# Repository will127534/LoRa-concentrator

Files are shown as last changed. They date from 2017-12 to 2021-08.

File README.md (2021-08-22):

# LoRa-concentrator

A Real opensource LoRa Gateway using SX1301/SX1308 and SX1255/SX1257
For RRI and RPI Zero

**Version 3**
---
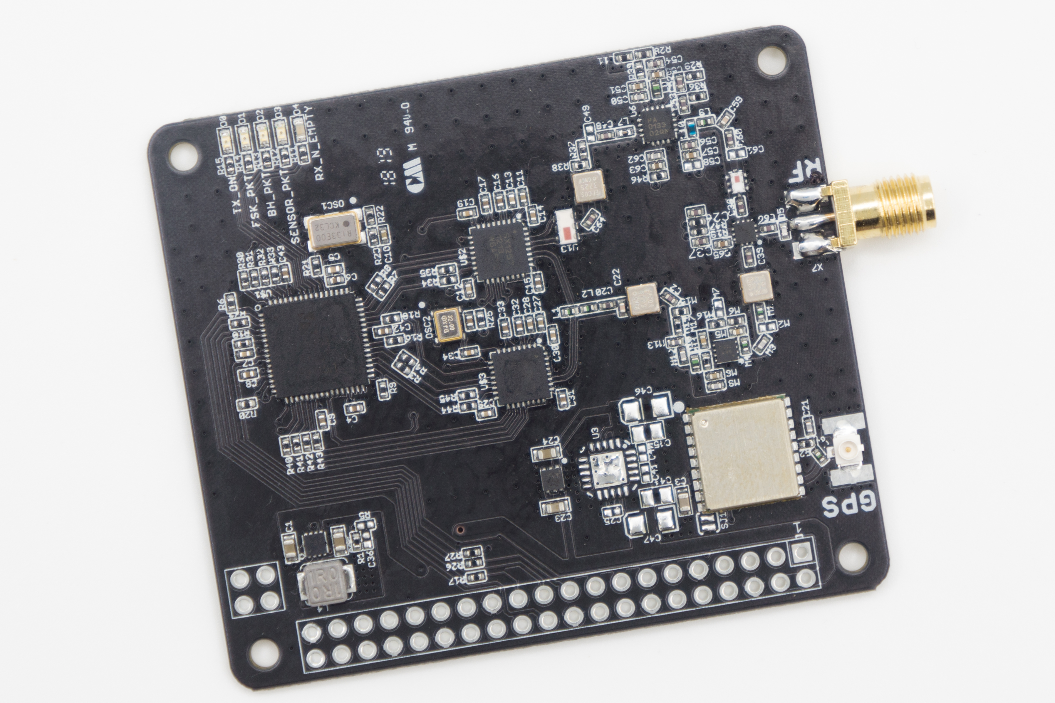
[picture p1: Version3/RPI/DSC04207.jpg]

Version 3 is designed for Raspberry Pi, same setup like Version 2, but I added LNA/PA and RF switch, and move to 4-layer board design
PA(RFPA0133) and RF switch(RFSW1012) is same as Microchip's LoRa gateway, but I changed LNA to SKY67150-396LF which have a much better Noise Figure(0.28dB).
Also note that I also used a wide bandwidth ceramic balun(800-1000Mhz) instead of discrete balun.

868Mhz and 915Mhz is mostly the same, just need to change four filter, both part number are in PCB files and BOM file. 

For power supply, 1.8V DC-DC step down has changed to TPS62061, but it is pin-to-pin replaceable with ETA3410. For 3.3V RF power, there is two option,
one is TPS7A470, which is a Ti's high-end LDO with 4 µVRMS noise, and 55dB PSRR, the other one is LP5912-3.3, which is cheaper but still gets 12 µVRMS noise and 75dB PSRR.

GPS module is still Max-7Q, which provide PPS to SX1301/8 and Raspberry Pi(GPIO05),
and provide NEMA through Raspberry Pi's UART port. There is a jumper for shuting down GPS module if you want to stack other board.

Lastly, it support PoE header on Raspberry Pi 3B+, so you can stack PoE hat on top of the board.(Just make it clear that the board doesn't have PoE on board, but just the pin header to support other PoE hat).

And is currently sold on Tindle!
https://www.tindie.com/products/will123321/sx1308-raspberry-pi-zero-lora-gateway-board/
https://www.tindie.com/products/will123321/sx1308-raspberry-pi-lora-gateway-board/

Update: 2021/08/22: The board has sold out!

**Version 2**
---
Version 2 is designed for Raspberry Pi and another board for Pi Zero


for Raspberry Pi, there is two SX125X, but for Pi Zero I strip down Radio_A for better layout.
Both of them have a Max-7Q GPS module, which provide PPS to SX1301 and Raspberry Pi(GPIO05),
and provide NEMA through Raspberry Pi's UART port. There's also a jumper for shuting down GPS module if you want to stack other board.

At the RF frontend, the main difference is that I didn't combine RX/TX using a RF switch,
and there is no on-board PA/LNA, but I did put a SAW filter. The reason not to is that I can use external LNA which is right under the antenna, there is a bias inductor right after RX port, which is connected to Raspberry Pi's 5V power rail.  

The current RPI version is designed for SX1257, but it is easy to migrate to SX1255, just put SX1255 on SX1257 and change RF passive components according to SX1255 datasheet.

I've tested both SX1255 & SX1257, and also two SX1301 connected to Raspberry Pi at the same time (there is a jumper for CE0/CE1).

last but not least, I've launch some High Altitude Balloon and using it as my multi-channel receiver. Which reach about 100Km by BW 125Khz CR 4/5 SF 7 @ 432Mhz with 16dBm power + MAX2640 LNA.

**Version 1**
---
note that I haven't get it working yet, stuck in PLL lock  
but SPI test seems to be OK.  



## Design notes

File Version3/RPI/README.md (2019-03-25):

# RPi IO Mapping

| Function | RPi Pin  | RPi IO Names |
| --- | --- | --- |
| SPI MOSI | 19 | SPI-MOSI, GPIO10 |
| SPI MISO | 21 | SPI-MISO, GPIO9 |
| SPI SCK | 23 | SPI-SCLK, GPIO11 |
| SPI CSN | 24 OR 26 | SPI-CS0, GPIO8 OR SPI-CS1, GPIO7 |
| Reset | 22 | GPIO25 |
| GPS UART TX | 10 | UART0-RX, GPIO15 |
| GPS UART RX | 8 | UART0-TX, GPIO14 |
| GPS PPS | 29 | GPIO5 |

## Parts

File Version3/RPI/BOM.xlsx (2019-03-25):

Qty | Value | Device | Package | Parts | Description
1 | LXES15AAA1-133 | D | C0402 | D5
1 | 0900BL18B100 | BALUN_1206 | BALUN_1206 | U13
1 | 0868LP15A020/0915LP15B026 | LowPassFilter | LowPassFilter | U$6
14 | 0R | R-0402 | R0402 | M16, R1, R9, R10, R17, R21, R22, R23, R24, R25, R26, R27, M14, L11
2 | 1000pF | CAP-0402 | C0402 | M5, M17
6 | 100R | R-0402 | R0402 | R3, R4, R7, R8, R16, R18
15 | 100nF | CAP-0402 | C0402 | C4, C6, C8, C9, C15, C16, C17, C18, C31, C32, C33, C42, C43, C63, C65
1 | 100nH | RF INDUCTOR | L0402 | M4
2 | 100pF | CAP-0402 | C0402 | C50, C62
8 | 10K | R-0402 | R0402 | R6, R20, R30, R32, R33, R40, R42, R43
1 | 10R | R-0402 | R0402 | R2
4 | 10nF | CAP-0402 | C0402 | C10, C11, C27, M8
1 | 10nH | RF INDUCTOR | L0402 | M10
2 | 10pF | CAP-0402 | C0402 | M9, M12
1 | 10uF | C-0603 | C0603 | C3
4 | 10uF | CAP-0603 | C0603 | C1, C23, C24, C35
1 | 150R | R-0402 | R0402 | R38
1 | 18nH | RF INDUCTOR | L0402 | L10
1 | 1K | CAP-0402 | C0402 | M15
2 | 1K | R-0402 | R0402 | R31, R41
2 | 1nF | CAP-0402 | C0402 | C19, C34
7 | 1uF | CAP-0402 | C0402 | C7, C12, C13, C14, C28, C29, C30
1 | 1uH | L'1616BZ' | 1616BZ | L4
1 | 2.2pF | CAP-0402 | C0402 | M13
3 | 2.2uF | CAP-0402 | C0402 | C51, C55, C57
1 | 2.7nH | RF INDUCTOR | L0402 | L9
1 | 20pF | CAP-0402 | C0402 | M3
1 | 22uF | CAP-0402 | C0402 | C5
1 | 3.9R | R-0402 | R0402 | R28
4 | 300R | R-0402 | R0402 | R19, R29, R36, R47
4 | 330R | R-0402 | R0402 | R34, R35, R44, R45
2 | 36.5R | R-0402 | R0402 | R37, R46
5 | 470R | R-0402 | R0402 | R11, R12, R13, R14, R15
1 | 49.9R | R-0402 | R0402 | R39
2 | 5.6pF | CAP-0402 | C0402 | C22, C59
1 | 562R | R-0402 | R0402 | M11
14 | 56pF | CAP-0402 | C0402 | C2, C20, C26, C37, C38, C39, C48, C52, C53, C54, C56, C60, C64, C66
1 | 6.8nH | RF INDUCTOR | L0402 | L8
1 | 8.2nH | CAP-0402 | C0402 | M1
1 | 8.2nH | RF INDUCTOR | L0402 | L7
1 | 9.1K | R-0402 | R0402 | M6
3 | B39921B3728U410/B39871B3717U410 | EPCOS_SAW_FILTER | EPCOS_SAW_FILTER | U$4, U$8, U$9
1 | GRM1555C1E470JZ01 | C-0402 | C0402 | C21
4 | Green | LED-0603 | LED-0603 | D0, D1, D2, D3
1 | LP5912 | LP5912 | WSON6 | U$5
1 | LQG15HS27NJ02 | RF INDUCTOR | L0402 | L6
1 | LQG15HS33NJ02D | RF INDUCTOR | L0402 | L1
1 | LQG15HS3N9C02D | RF INDUCTOR | L0402 | L2
1 | MAX-7Q-0(18p-10x9.6mm) | MODULE-GPS-SMD-MAX-7Q-0(18P-9.6X10MM) | GPS18P-SMD-1.1-10X9.6MM | GPS
1 | 32Mhz TXCO | OSCILLATOR | CRYSTAL-OSC-SMD-3.2X2.5 | OSC2
1 | 133Mhz | OSCILLATOR5X3-PIN1-INDICATED | CRYSTAL-OSC-SMD-5X3 | OSC1
1 | RASPI_BOARD_B+#_H | RASPI_BOARD_B+#_H | RASPI_BOARD_B+HAT | X1
1 | RFPA0133 | RFPA0133 | QFN16-3X3MM | U6
1 | RFSW1012 | RFSW1012 | QFN12-2X2MM | U$7
1 | Red | LED-0603 | LED-0603 | D4
1 | SKY67150_396LF | SKY67150_396LF | 8DFN | U$10
2 | SX1255 | SX1255 | QFN32G-0.5-5X5MM | U$2, U$3
1 | SX1301 | SX1301 | QFN64G-0.5-9X9MM | U$1
1 | TPS62061 | PMIC-ETA3410D2I-T(DFN8-2X2)WSON | WSON | U1
1 | uFL | SMACONNECTOR_EDGE_UFL | SMA_EDGELAUNCH_UFL | X4
1 | SMA | SMACONNECTOR_EDGE_UFL | SMA_EDGELAUNCH_UFL | X7

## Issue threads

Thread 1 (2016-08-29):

bad voltage regulator

nestorayuso, 2016-08-29:
Hi,

I see in your schematic you are using a XC6204 voltage regulators for 1.8 and 3.3 outputs from a 5v source.
This regulator has only 150mA max output current. This is insufficient.

SX1301 need 550mA typ, 750mA max @ 1.8v and 5mA typ, 10mA max @ 3.3v.

Even if you put a bigger LDO with 1A or more, the LDO will get very very hot, it will dissipate (5-1.8)*0.55= 1.76W of energy in hot.
I recommend to use a (step-down, DCDC converter...) switching regulator not linear regulator.

will127534, 2016-08-30:
Hi nestorayuso,
Thanks for pointing out the problem.
XC6204 is actually just for general SOT-23 LDO package, I solder RT9193-18PB for 1.8v and SPX3819M5-L-3.3 for 3.3v.

But you are right, it is insufficient for SX1301, I'll change the 1.8v power rail design to step-down next version.

Thanks for the comment.

hallard, 2016-08-31:
For testing may be you can use dual output DC/DC step down like that,
http://www.ebay.com/itm/DC-DC-Buck-Converter-Step-Down-Module-Power-Supply-1-5v-1-8v-3-3v-2A-Dual-Output-/262539347063

Not sure of quality but may be testing worth it.

will127534, 2016-09-02:
Hi hallard,
thanks for the advice, maybe I'll look for that IC, looks very nice (2-in-1 chip)
I'm using Lab power supply for testing though.
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
well I guess that SX1301 is dead, 1.8V rail only output 80mA, nowhere near the 700mA

This is the Log of util_pkt_logger:

loragw_pkt_logger: INFO: found global configuration file global_conf.json, trying to parse it
loragw_pkt_logger: INFO: global_conf.json does contain a JSON object named SX1301_conf, parsing SX1301 parameters
loragw_pkt_logger: INFO: lorawan_public 1, clksrc 0
lgw_board_setconf:361: Note: board configuration; lorawan_public:1, clksrc:0
loragw_pkt_logger: INFO: radio 0 enabled (type SX1255), center frequency 433000000, RSSI offset -166.000000, tx enabled 1
lgw_rxrf_setconf:415: Note: rf_chain 0 configuration; en:1 freq:433000000 rssi_offset:-166.000000 radio_type:1 tx_enable:1
loragw_pkt_logger: INFO: radio 1 enabled (type SX1255), center frequency 437000000, RSSI offset -166.000000, tx enabled 0
lgw_rxrf_setconf:415: Note: rf_chain 1 configuration; en:1 freq:437000000 rssi_offset:-166.000000 radio_type:1 tx_enable:0
loragw_pkt_logger: INFO: LoRa multi-SF channel 0 enabled, radio 1 selected, IF -400000 Hz, 125 kHz bandwidth, SF 7 to 12
lgw_rxif_setconf:519: Note: LoRa 'multi' if_chain 0 configuration; en:1 freq:-400000 SF_mask:0x7e
loragw_pkt_logger: INFO: LoRa multi-SF channel 1 enabled, radio 1 selected, IF -200000 Hz, 125 kHz bandwidth, SF 7 to 12
lgw_rxif_setconf:519: Note: LoRa 'multi' if_chain 1 configuration; en:1 freq:-200000 SF_mask:0x7e
loragw_pkt_logger: INFO: LoRa multi-SF channel 2 enabled, radio 1 selected, IF 0 Hz, 125 kHz bandwidth, SF 7 to 12
lgw_rxif_setconf:519: Note: LoRa 'multi' if_chain 2 configuration; en:1 freq:0 SF_mask:0x7e
loragw_pkt_logger: INFO: LoRa multi-SF channel 3 enabled, radio 0 selected, IF -400000 Hz, 125 kHz bandwidth, SF 7 to 12
lgw_rxif_setconf:519: Note: LoRa 'multi' if_chain 3 configuration; en:1 freq:-400000 SF_mask:0x7e
loragw_pkt_logger: INFO: LoRa multi-SF channel 4 enabled, radio 0 selected, IF -200000 Hz, 125 kHz bandwidth, SF 7 to 12
lgw_rxif_setconf:519: Note: LoRa 'multi' if_chain 4 configuration; en:1 freq:-200000 SF_mask:0x7e
loragw_pkt_logger: INFO: LoRa multi-SF channel 5 enabled, radio 0 selected, IF 0 Hz, 125 kHz bandwidth, SF 7 to 12
lgw_rxif_setconf:519: Note: LoRa 'multi' if_chain 5 configuration; en:1 freq:0 SF_mask:0x7e
loragw_pkt_logger: INFO: LoRa multi-SF channel 6 enabled, radio 0 selected, IF 200000 Hz, 125 kHz bandwidth, SF 7 to 12
lgw_rxif_setconf:519: Note: LoRa 'multi' if_chain 6 configuration; en:1 freq:200000 SF_mask:0x7e
loragw_pkt_logger: INFO: LoRa multi-SF channel 7 enabled, radio 0 selected, IF 400000 Hz, 125 kHz bandwidth, SF 7 to 12
lgw_rxif_setconf:519: Note: LoRa 'multi' if_chain 7 configuration; en:1 freq:400000 SF_mask:0x7e
loragw_pkt_logger: INFO: LoRa standard channel enabled, radio 1 selected, IF -200000 Hz, 250000 Hz bandwidth, SF 7
lgw_rxif_setconf:493: Note: LoRa 'std' if_chain 8 configuration; en:1 freq:-200000 bw:2 dr:2
loragw_pkt_logger: INFO: FSK channel enabled, radio 1 selected, IF 300000 Hz, 125000 Hz bandwidth, 50000 bps datarate
lgw_rxif_setconf:549: Note: FSK if_chain 9 configuration; en:1 freq:300000 bw:3 dr:50000 (50000 real dr) sync:0xC194C1
loragw_pkt_logger: INFO: global_conf.json does contain a JSON object named gateway_conf, parsing gateway parameters
loragw_pkt_logger: INFO: gateway MAC address is configured to AA555A9000000000
loragw_pkt_logger: INFO: found local configuration file local_conf.json, trying to parse it
loragw_pkt_logger: INFO: local_conf.json does not contain a JSON object named SX1301_conf
loragw_pkt_logger: INFO: local_conf.json does contain a JSON object named gateway_conf, parsing gateway parameters
loragw_pkt_logger: INFO: gateway MAC address is configured to AA555A9000000101
lgw_connect:524: INFO: no FPGA detected or version not supported (v0)
Note: success connecting the concentrator
setup_sx125x:495: Note: SX125x #0 version register returned 0x07
setup_sx125x:500: Note: SX125x #0 clock output enabled
setup_sx125x:557: Note: SX125x #0 PLL start (attempt 1)
setup_sx125x:495: Note: SX125x #1 version register returned 0x1f
setup_sx125x:503: Note: SX125x #1 clock output disabled
setup_sx125x:557: Note: SX125x #1 PLL start (attempt 1)
ERROR: Failed to load fw 1
ERROR: Version of calibration firmware not expected, actual:0 expected:2
loragw_pkt_logger: ERROR: failed to start the concentrator

Seems that PLL is locked!

nestorayuso, 2016-09-22:
Any progress?

550mA is when SX1301 is full running (8 MultiSF + LoRa + FSK receivers enabled), until not enabled 80mA can be a good value.

About PLL lock,
do you have the 133MHz oscilator running?
do you have the 32MHz oscillator running and routed to both sx1255 radios?
which one of the sx1255 radios provides clock back to the SX1301?
is sx1301 configured to receive clock source from that radio?

will127534, 2016-09-27:
133Mhz and 32Mhz are both running, I can see both osc are working, alsothe 32Mhz output from SX1255 to SX1301, seems OK
Not sure for the 133Mhz osc though, I'm using LVCMOS/LVTTL compatible osc.
32Mhz is for both SX1255, and I connected Radio A's 32Mhz out to SX1301.

yuqian08, 2016-12-10:
Hi Will, this is very interesting board, we are working on design air quality sensors project based on Lora, but we doing the node with Microchip RN2903/2483, and have some productions released, maybe we can have some corporation in future :)
I have a question, where you got those SX1301 documents and chips? from Semtech? thank you.

will127534, 2017-07-17:
Hi yuqian08 ,
I just noticed that Semtech release the full datasheet for SX1301 and SX1308.

will127534, 2017-09-01:
I've change 1.8V power reg to step-down, problem seems to be solved.
So closing this issue, thanks nestorayuso for pointing out this issue.

Closed 2017-09-01.

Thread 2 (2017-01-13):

ERROR: Version of calibration firmware not expected

will127534, 2017-01-13:
Currently this board still stuck on this problem,
Register Test passed, and I can confirm that the firmware is correct.
Here is the test_loragw_reg result.
Beginning of test for loragw_reg.c
Start of register verification
+++MATCH+++ reg number 0 read: 0 (0) default: 0 (0)
+++MATCH+++ reg number 1 read: 0 (0) default: 0 (0)
+++MATCH+++ reg number 2 read: 103 (67) default: 103 (67)
+++MATCH+++ reg number 3 read: 0 (0) default: 0 (0)
###MISMATCH### reg number 4 read: 204 (cc) default: 0 (0)
+++MATCH+++ reg number 5 read: 0 (0) default: 0 (0)
+++MATCH+++ reg number 6 read: 0 (0) default: 0 (0)
+++MATCH+++ reg number 7 read: 0 (0) default: 0 (0)
###MISMATCH### reg number 8 read: 20 (14) default: 0 (0)
+++MATCH+++ reg number 9 read: 0 (0) default: 0 (0)
###MISMATCH### reg number 10 read: 138 (8a) default: 0 (0)
+++MATCH+++ reg number 11 read: 0 (0) default: 0 (0)
+++MATCH+++ reg number 12 read: 0 (0) default: 0 (0)
+++MATCH+++ reg number 13 read: 0 (0) default: 0 (0)
+++MATCH+++ reg number 14 read: 0 (0) default: 0 (0)
+++MATCH+++ reg number 15 read: 0 (0) default: 0 (0)
+++MATCH+++ reg number 16 read: 0 (0) default: 0 (0)
+++MATCH+++ reg number 17 read: 0 (0) default: 0 (0)
+++MATCH+++ reg number 18 read: 0 (0) default: 0 (0)
+++MATCH+++ reg number 19 read: 1 (1) default: 1 (1)
+++MATCH+++ reg number 20 read: 1 (1) default: 1 (1)
+++MATCH+++ reg number 21 read: 0 (0) default: 0 (0)
+++MATCH+++ reg number 22 read: 0 (0) default: 0 (0)
+++MATCH+++ reg number 23 read: 0 (0) default: 0 (0)
+++MATCH+++ reg number 24 read: 0 (0) default: 0 (0)
+++MATCH+++ reg number 25 read: 0 (0) default: 0 (0)
+++MATCH+++ reg number 26 read: 0 (0) default: 0 (0)
+++MATCH+++ reg number 27 read: 0 (0) default: 0 (0)
+++MATCH+++ reg number 28 read: 0 (0) default: 0 (0)
+++MATCH+++ reg number 29 read: 0 (0) default: 0 (0)
+++MATCH+++ reg number 30 read: 0 (0) default: 0 (0)
+++MATCH+++ reg number 31 read: 0 (0) default: 0 (0)
+++MATCH+++ reg number 32 read: 0 (0) default: 0 (0)
+++MATCH+++ reg number 33 read: 0 (0) default: 0 (0)
+++MATCH+++ reg number 34 read: 0 (0) default: 0 (0)
+++MATCH+++ reg number 35 read: 0 (0) default: 0 (0)
+++MATCH+++ reg number 36 read: 0 (0) default: 0 (0)
+++MATCH+++ reg number 37 read: 0 (0) default: 0 (0)
+++MATCH+++ reg number 38 read: 0 (0) default: 0 (0)
+++MATCH+++ reg number 39 read: 0 (0) default: 0 (0)
+++MATCH+++ reg number 40 read: 0 (0) default: 0 (0)
+++MATCH+++ reg number 41 read: 0 (0) default: 0 (0)
+++MATCH+++ reg number 42 read: 0 (0) default: 0 (0)
+++MATCH+++ reg number 43 read: 0 (0) default: 0 (0)
+++MATCH+++ reg number 44 read: 0 (0) default: 0 (0)
+++MATCH+++ reg number 45 read: 0 (0) default: 0 (0)
+++MATCH+++ reg number 46 read: 0 (0) default: 0 (0)
+++MATCH+++ reg number 47 read: 0 (0) default: 0 (0)
+++MATCH+++ reg number 48 read: 0 (0) default: 0 (0)
+++MATCH+++ reg number 49 read: 0 (0) default: 0 (0)
+++MATCH+++ reg number 50 read: 0 (0) default: 0 (0)
+++MATCH+++ reg number 51 read: 0 (0) default: 0 (0)
+++MATCH+++ reg number 52 read: 0 (0) default: 0 (0)
+++MATCH+++ reg number 53 read: 0 (0) default: 0 (0)
+++MATCH+++ reg number 54 read: 0 (0) default: 0 (0)
+++MATCH+++ reg number 55 read: 0 (0) default: 0 (0)
+++MATCH+++ reg number 56 read: 0 (0) default: 0 (0)
+++MATCH+++ reg number 57 read: 0 (0) default: 0 (0)
+++MATCH+++ reg number 58 read: 0 (0) default: 0 (0)
+++MATCH+++ reg number 59 read: 0 (0) default: 0 (0)
+++MATCH+++ reg number 60 read: 0 (0) default: 0 (0)
+++MATCH+++ reg number 61 read: 0 (0) default: 0 (0)
+++MATCH+++ reg number 62 read: 0 (0) default: 0 (0)
+++MATCH+++ reg number 63 read: 0 (0) default: 0 (0)
+++MATCH+++ reg number 64 read: 0 (0) default: 0 (0)
+++MATCH+++ reg number 65 read: 0 (0) default: 0 (0)
+++MATCH+++ reg number 66 read: 0 (0) default: 0 (0)
+++MATCH+++ reg number 67 read: 0 (0) default: 0 (0)
+++MATCH+++ reg number 68 read: 0 (0) default: 0 (0)
+++MATCH+++ reg number 69 read: 0 (0) default: 0 (0)
+++MATCH+++ reg number 70 read: 0 (0) default: 0 (0)
+++MATCH+++ reg number 71 read: 0 (0) default: 0 (0)
+++MATCH+++ reg number 72 read: 0 (0) default: 0 (0)
+++MATCH+++ reg number 73 read: 0 (0) default: 0 (0)
+++MATCH+++ reg number 74 read: 0 (0) default: 0 (0)
+++MATCH+++ reg number 75 read: 0 (0) default: 0 (0)
+++MATCH+++ reg number 76 read: 0 (0) default: 0 (0)
+++MATCH+++ reg number 77 read: 0 (0) default: 0 (0)
+++MATCH+++ reg number 78 read: 0 (0) default: 0 (0)
+++MATCH+++ reg number 79 read: 0 (0) default: 0 (0)
+++MATCH+++ reg number 80 read: 0 (0) default: 0 (0)
+++MATCH+++ reg number 81 read: 0 (0) default: 0 (0)
+++MATCH+++ reg number 82 read: 1 (1) default: 1 (1)
+++MATCH+++ reg number 83 read: 1 (1) default: 1 (1)
+++MATCH+++ reg number 84 read: 0 (0) default: 0 (0)
+++MATCH+++ reg number 85 read: 1 (1) default: 1 (1)
+++MATCH+++ reg number 86 read: 0 (0) default: 0 (0)
+++MATCH+++ reg number 87 read: 0 (0) default: 0 (0)
+++MATCH+++ reg number 88 read: 0 (0) default: 0 (0)
+++MATCH+++ reg number 89 read: 0 (0) default: 0 (0)
+++MATCH+++ reg number 90 read: 7 (7) default: 7 (7)
+++MATCH+++ reg number 91 read: 240 (f0) default: 240 (f0)
+++MATCH+++ reg number 92 read: -384 (fffffe80) default: -384 (fffffe80)
+++MATCH+++ reg number 93 read: -128 (ffffff80) default: -128 (ffffff80)
+++MATCH+++ reg number 94 read: 128 (80) default: 128 (80)
+++MATCH+++ reg number 95 read: 384 (180) default: 384 (180)
+++MATCH+++ reg number 96 read: -384 (fffffe80) default: -384 (fffffe80)
+++MATCH+++ reg number 97 read: -128 (ffffff80) default: -128 (ffffff80)
+++MATCH+++ reg number 98 read: 128 (80) default: 128 (80)
+++MATCH+++ reg number 99 read: 384 (180) default: 384 (180)
+++MATCH+++ reg number 100 read: 0 (0) default: 0 (0)
+++MATCH+++ reg number 101 read: 0 (0) default: 0 (0)
+++MATCH+++ reg number 102 read: 0 (0) default: 0 (0)
+++MATCH+++ reg number 103 read: 7 (7) default: 7 (7)
+++MATCH+++ reg number 104 read: 0 (0) default: 0 (0)
+++MATCH+++ reg number 105 read: 0 (0) default: 0 (0)
+++MATCH+++ reg number 106 read: 0 (0) default: 0 (0)
+++MATCH+++ reg number 107 read: 0 (0) default: 0 (0)
+++MATCH+++ reg number 108 read: 0 (0) default: 0 (0)
+++MATCH+++ reg number 109 read: 0 (0) default: 0 (0)
+++MATCH+++ reg number 110 read: 0 (0) default: 0 (0)
+++MATCH+++ reg number 111 read: 0 (0) default: 0 (0)
+++MATCH+++ reg number 112 read: 0 (0) default: 0 (0)
+++MATCH+++ reg number 113 read: 1 (1) default: 1 (1)
+++MATCH+++ reg number 114 read: 1 (1) default: 1 (1)
+++MATCH+++ reg number 115 read: 1 (1) default: 1 (1)
+++MATCH+++ reg number 116 read: 1 (1) default: 1 (1)
+++MATCH+++ reg number 117 read: 1 (1) default: 1 (1)
+++MATCH+++ reg number 118 read: 1 (1) default: 1 (1)
+++MATCH+++ reg number 119 read: 4 (4) default: 4 (4)
+++MATCH+++ reg number 120 read: 4 (4) default: 4 (4)
+++MATCH+++ reg number 121 read: 4 (4) default: 4 (4)
+++MATCH+++ reg number 122 read: 4 (4) default: 4 (4)
+++MATCH+++ reg number 123 read: 4 (4) default: 4 (4)
+++MATCH+++ reg number 124 read: 4 (4) default: 4 (4)
+++MATCH+++ reg number 125 read: 4 (4) default: 4 (4)
+++MATCH+++ reg number 126 read: 4 (4) default: 4 (4)
+++MATCH+++ reg number 127 read: 5 (5) default: 5 (5)
+++MATCH+++ reg number 128 read: 0 (0) default: 0 (0)
+++MATCH+++ reg number 129 read: 4092 (ffc) default: 4092 (ffc)
+++MATCH+++ reg number 130 read: 7 (7) default: 7 (7)
+++MATCH+++ reg number 131 read: 0 (0) default: 0 (0)
+++MATCH+++ reg number 132 read: 0 (0) default: 0 (0)
+++MATCH+++ reg number 133 read: 0 (0) default: 0 (0)
+++MATCH+++ reg number 134 read: 1 (1) default: 1 (1)
+++MATCH+++ reg number 135 read: 1 (1) default: 1 (1)
+++MATCH+++ reg number 136 read: 0 (0) default: 0 (0)
+++MATCH+++ reg number 137 read: 0 (0) default: 0 (0)
+++MATCH+++ reg number 138 read: 0 (0) default: 0 (0)
+++MATCH+++ reg number 139 read: 29 (1d) default: 29 (1d)
+++MATCH+++ reg number 140 read: 9 (9) default: 9 (9)
+++MATCH+++ reg number 141 read: 2 (2) default: 2 (2)
+++MATCH+++ reg number 142 read: 1 (1) default: 1 (1)
+++MATCH+++ reg number 143 read: 0 (0) default: 0 (0)
+++MATCH+++ reg number 144 read: 1 (1) default: 1 (1)
+++MATCH+++ reg number 145 read: 2 (2) default: 2 (2)
+++MATCH+++ reg number 146 read: 10 (a) default: 10 (a)
+++MATCH+++ reg number 147 read: 1 (1) default: 1 (1)
+++MATCH+++ reg number 148 read: 1 (1) default: 1 (1)
+++MATCH+++ reg number 149 read: 8 (8) default: 8 (8)
+++MATCH+++ reg number 150 read: 2 (2) default: 2 (2)
+++MATCH+++ reg number 151 read: 0 (0) default: 0 (0)
+++MATCH+++ reg number 152 read: 255 (ff) default: 255 (ff)
+++MATCH+++ reg number 153 read: 1 (1) default: 1 (1)
+++MATCH+++ reg number 154 read: 0 (0) default: 0 (0)
+++MATCH+++ reg number 155 read: 8 (8) default: 8 (8)
+++MATCH+++ reg number 156 read: 7 (7) default: 7 (7)
+++MATCH+++ reg number 157 read: 1 (1) default: 1 (1)
+++MATCH+++ reg number 158 read: 1 (1) default: 1 (1)
+++MATCH+++ reg number 159 read: 1 (1) default: 1 (1)
+++MATCH+++ reg number 160 read: 1 (1) default: 1 (1)
+++MATCH+++ reg number 161 read: 1 (1) default: 1 (1)
+++MATCH+++ reg number 162 read: 0 (0) default: 0 (0)
+++MATCH+++ reg number 163 read: 0 (0) default: 0 (0)
+++MATCH+++ reg number 164 read: 0 (0) default: 0 (0)
+++MATCH+++ reg number 165 read: 0 (0) default: 0 (0)
+++MATCH+++ reg number 166 read: 0 (0) default: 0 (0)
+++MATCH+++ reg number 167 read: 0 (0) default: 0 (0)
+++MATCH+++ reg number 168 read: 1 (1) default: 1 (1)
+++MATCH+++ reg number 169 read: 32 (20) default: 32 (20)
+++MATCH+++ reg number 170 read: 100 (64) default: 100 (64)
+++MATCH+++ reg number 171 read: 100 (64) default: 100 (64)
+++MATCH+++ reg number 172 read: 7 (7) default: 7 (7)
+++MATCH+++ reg number 173 read: 5 (5) default: 5 (5)
+++MATCH+++ reg number 174 read: 8 (8) default: 8 (8)
+++MATCH+++ reg number 175 read: 0 (0) default: 0 (0)
+++MATCH+++ reg number 176 read: 0 (0) default: 0 (0)
+++MATCH+++ reg number 177 read: 0 (0) default: 0 (0)
+++MATCH+++ reg number 178 read: 0 (0) default: 0 (0)
+++MATCH+++ reg number 179 read: 0 (0) default: 0 (0)
+++MATCH+++ reg number 180 read: 0 (0) default: 0 (0)
+++MATCH+++ reg number 181 read: 0 (0) default: 0 (0)
+++MATCH+++ reg number 182 read: 0 (0) default: 0 (0)
+++MATCH+++ reg number 183 read: 0 (0) default: 0 (0)
+++MATCH+++ reg number 184 read: 1 (1) default: 1 (1)
+++MATCH+++ reg number 185 read: 2 (2) default: 2 (2)
+++MATCH+++ reg number 186 read: 0 (0) default: 0 (0)
+++MATCH+++ reg number 187 read: 0 (0) default: 0 (0)
+++MATCH+++ reg number 188 read: 0 (0) default: 0 (0)
+++MATCH+++ reg number 189 read: 0 (0) default: 0 (0)
+++MATCH+++ reg number 190 read: 0 (0) default: 0 (0)
+++MATCH+++ reg number 191 read: 0 (0) default: 0 (0)
+++MATCH+++ reg number 192 read: 0 (0) default: 0 (0)
+++MATCH+++ reg number 193 read: 0 (0) default: 0 (0)
+++MATCH+++ reg number 194 read: 5 (5) default: 5 (5)
+++MATCH+++ reg number 195 read: 0 (0) default: 0 (0)
+++MATCH+++ reg number 196 read: 1 (1) default: 1 (1)
+++MATCH+++ reg number 197 read: 0 (0) default: 0 (0)
+++MATCH+++ reg number 198 read: 0 (0) default: 0 (0)
+++MATCH+++ reg number 199 read: 0 (0) default: 0 (0)
+++MATCH+++ reg number 200 read: 0 (0) default: 0 (0)
+++MATCH+++ reg number 201 read: 1 (1) default: 1 (1)
+++MATCH+++ reg number 202 read: 1 (1) default: 1 (1)
+++MATCH+++ reg number 203 read: 2 (2) default: 2 (2)
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
9600, 2017-01-29:
I saw something like this with an iC880A concentrator board when I accidentally had the current limited on a bench PSU set too low. It sort of appeared to work, but I got bogus messages about firmware versions being wrong and the packet forwarder would not start.

will127534, 2017-09-01:
I think the problem might cause by the reset line, I didn't have a resistor to pull down.
I left it floating during first couple time of testing,  and it might blow up the whole chip.

Anyway, this problem is not happened on my version 2, so closing this issue.

Closed 2017-09-01.

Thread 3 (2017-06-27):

Usage

alexanderplanar, 2017-06-27:
Hi! I'm interesting this project, I need to create a simple gateway for LoRa.
How to use this board? I mean, this is project, as I understand, provides the physical layer, what I should use  to connect this layer to LoRa server?
For example, I found the project group [LoRa-net on github](https://github.com/Lora-net), I installed and setup LoRa-Gateway-Bridge, LoRa-Network-Server and LoRa-Application-Server on VirtualBox.
How to put it together?

mikini, 2017-07-06:
As I understand it, this board carries similar functionality as the [IMST iC880a concentrator](http://webshop.imst.de/ic880a-spi-lorawan-concentrator-868mhz.html) often used in [DIY TTN gateways](https://github.com/ttn-zh/ic880a-gateway/wiki) together with a Raspberry Pi. See the setup with a Pi in issue #1.

This board however is completely open hardware, but at the moment the design only carries a [sx1255](http://www.semtech.com/wireless-rf/rf-transceivers/sx1255/) (for 915MHz regions). For me located in Europe I'd need it tweaked for a [sx1257](http://www.semtech.com/wireless-rf/rf-transceivers/sx1257/) (868MHz) to be useful. I haven't looked into the details, yet, but are very interested too.

Seems like it is still under bring-up, though.

will127534, 2017-09-01:
Bring-up is completed guys, using version 2 hardware.
You can changed to SX1257 simply replace SX1255, it is pin compatible, but needs to change RF filter according to datasheet.

Closed 2017-09-01.

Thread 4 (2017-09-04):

Unreliable RF receive

will127534, 2017-09-04:
Testing Setup: one Transmitter @ 433.5Mhz, config Radio_B to 433.2Mhz and two channel with IF 0Khz and +3Khz.

Problem: the transmitter is transmitting package one per second (confirm by other SX1278), but SX1301 cannot receive package reliably, receive a package for a couple seconds, as the log show below.

> pi@raspberrypi:~/lora_gateway/util_pkt_logger $ ./util_pkt_logger
loragw_pkt_logger: INFO: found global configuration file global_conf.json, trying to parse it
loragw_pkt_logger: INFO: global_conf.json does contain a JSON object named SX1301_conf, parsing SX1301 parameters
loragw_pkt_logger: INFO: lorawan_public 1, clksrc 1
lgw_board_setconf:427: Note: board configuration; lorawan_public:1, clksrc:1
loragw_pkt_logger: INFO: radio 0 enabled (type SX1255), center frequency 433000000, RSSI offset -166.000000, tx enabled 0, tx_notch_freq 0
lgw_rxrf_setconf:488: Note: rf_chain 0 configuration; en:1 freq:433000000 rssi_offset:-166.000000 radio_type:1 tx_enable:0 tx_notch_freq:0
loragw_pkt_logger: INFO: radio 1 enabled (type SX1255), center frequency 433200000, RSSI offset -166.000000, tx enabled 1, tx_notch_freq 0
lgw_rxrf_setconf:476: WARNING: NOT A VALID TX NOTCH FILTER FREQUENCY [126000..250000]Hz
lgw_rxrf_setconf:488: Note: rf_chain 1 configuration; en:1 freq:433200000 rssi_offset:-166.000000 radio_type:1 tx_enable:1 tx_notch_freq:0
loragw_pkt_logger: INFO: LoRa multi-SF channel 0 enabled, radio 1 selected, IF 0 Hz, 125 kHz bandwidth, SF 7 to 12
lgw_rxif_setconf:607: Note: LoRa 'multi' if_chain 0 configuration; en:1 freq:0 SF_mask:0x7e
loragw_pkt_logger: INFO: LoRa multi-SF channel 1 enabled, radio 1 selected, IF 300000 Hz, 125 kHz bandwidth, SF 7 to 12
lgw_rxif_setconf:607: Note: LoRa 'multi' if_chain 1 configuration; en:1 freq:300000 SF_mask:0x7e
loragw_pkt_logger: INFO: LoRa multi-SF channel 2 disabled
lgw_rxif_setconf:515: Note: if_chain 2 disabled
loragw_pkt_logger: INFO: LoRa multi-SF channel 3 disabled
lgw_rxif_setconf:515: Note: if_chain 3 disabled
loragw_pkt_logger: INFO: LoRa multi-SF channel 4 disabled
lgw_rxif_setconf:515: Note: if_chain 4 disabled
loragw_pkt_logger: INFO: LoRa multi-SF channel 5 disabled
lgw_rxif_setconf:515: Note: if_chain 5 disabled
loragw_pkt_logger: INFO: LoRa multi-SF channel 6 disabled
lgw_rxif_setconf:515: Note: if_chain 6 disabled
loragw_pkt_logger: INFO: LoRa multi-SF channel 7 disabled
lgw_rxif_setconf:515: Note: if_chain 7 disabled
loragw_pkt_logger: INFO: LoRa standard channel 8 disabled
lgw_rxif_setconf:515: Note: if_chain 8 disabled
loragw_pkt_logger: INFO: FSK channel 8 disabled
lgw_rxif_setconf:515: Note: if_chain 9 disabled
loragw_pkt_logger: INFO: global_conf.json does contain a JSON object named gateway_conf, parsing gateway parameters
loragw_pkt_logger: INFO: gateway MAC address is configured to AA555A0000000000
loragw_pkt_logger: INFO: found local configuration file local_conf.json, trying to parse it
loragw_pkt_logger: INFO: local_conf.json does not contain a JSON object named SX1301_conf
loragw_pkt_logger: INFO: local_conf.json does contain a JSON object named gateway_conf, parsing gateway parameters
loragw_pkt_logger: INFO: gateway MAC address is configured to AA555A0000000101
lgw_start:819: Note: calibration started (time: 2300 ms)
lgw_start:840: Note: calibration finished (status = 197)
WARNING: calibration could not access radio A
WARNING: problem in calibration of radio A for image rejection
WARNING: problem in calibration of radio B for image rejection
Info: Initialising AGC firmware...
Info: putting back original RADIO_SELECT value
loragw_pkt_logger: INFO: concentrator started, packet can now be received
loragw_pkt_logger: INFO: Now writing to log file pktlog_AA555A0000000101_20170904T022342Z.csv
lgw_receive:1151: FIFO content: 1 10 0 5 20
lgw_receive:1170: [1 17]
Note: LoRa packet
"2017-09-04 02:23:46.551Z", 433500000,1, 1,-85, +9.8,14020300009E09E2E5C447840200000000000000000000000000000000000000"
lgw_receive:1151: FIFO content: 1 40 0 5 20
lgw_receive:1170: [1 17]
Note: LoRa packet
"2017-09-04 02:23:57.570Z", 433500000,1, 1,-85, +8.0,1F020300009E0974E6C4477F0200000000000000000000000000000000000000"
lgw_receive:1151: FIFO content: 1 70 0 5 20
lgw_receive:1170: [1 17]
Note: LoRa packet
"2017-09-04 02:24:18.558Z", 433500000,1, 1,-85,+11.2,34020300009C0940E5C447840200000000000000000000000000000000000000"
lgw_receive:1151: FIFO content: 1 a0 0 5 20
lgw_receive:1170: [1 17]
Note: LoRa packet
"2017-09-04 02:24:27.555Z", 433500000,1, 1,-81,+11.2,3D020300009E0916E6C447820200000000000000000000000000000000000000"
lgw_receive:1151: FIFO content: 1 d0 0 5 20
lgw_receive:1170: [1 17]
Note: LoRa packet
"2017-09-04 02:24:32.579Z", 433500000,1, 1,-76, +9.0,42020300009E095AE5C447810200000000000000000000000000000000000000"
lgw_receive:1151: FIFO content: 1 0 1 5 20
lgw_receive:1170: [1 17]
Note: LoRa packet
"2017-09-04 02:24:59.563Z", 433500000,1, 1,-79, +9.2,5D02030000A0096AE5C447830200000000000000000000000000000000000000"

The problem may cause by
1. Unstable Crystal (I'm using normal OSC now)
2. missing inductor at SX1255 input RF
3. missing SAW

So currently I'm going to get some TCXO, inductor, and SAW to see if any of them helps.

will127534, 2017-09-04:
also note that if I'm using single channel with SX1255 @ 433.5Mhz and IF =0Khz
I can not even receive a single package.

will127534, 2017-09-04:
TCXO doesn't help, confirmed.

will127534, 2017-09-04:
OK, solved the problem
I'm using radiohead and Arduino to transmit LoRa packet
Which is using LoRa Private Sync Word, so I need to adjust Gateway to Private mode.

Closed 2017-09-04.

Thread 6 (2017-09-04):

problem in calibration of radio B for image rejection

will127534, 2017-09-04:
Not sure what happened, but it keeps notify this error

> lgw_start:845: Note: calibration finished (status = 197)
WARNING: problem in calibration of radio B for image rejection

Closed 2018-05-26.

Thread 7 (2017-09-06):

About the value of Resistance, capacitance, inductance

hyklkd, 2017-09-06:
Hello, I have download your project and found that I can't get the value of Resistance, capacitance, inductance.Could you please show me you BOM?Thank you!

will127534, 2017-10-03:
I'm currently choosing the values for PCBA, so I'll push version 2.1 later, maybe before the end of the month.

will127534, 2017-12-01:
Values for 915Mhz are up!

Closed 2017-12-01.

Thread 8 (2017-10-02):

Values

Hoel, 2017-10-02:
Hi, i am interested in such concentrator for long range temperature humidity measurements (SHT21), i notice all values are removed, any chance you update the file or follow b email?
Thank you.

will127534, 2017-10-03:
Hi hoel,
I'm currently choosing the values for PCBA, so I'll push version 2.1 later, maybe before the end of the month.

will127534, 2017-12-01:
Values for 915Mhz are up!

Closed 2017-12-01.

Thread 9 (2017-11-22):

great project！

shujun, 2017-11-22:
Great project, Merge the gateway with Raspberry pi is a good idea.
Is NDA going to be a problem?And what's the progress and roadmap?

will127534, 2017-11-23:
Thanks!
I didn't signed any NDA, so its not going to be a problem IMAO.
Currently I'm building a version for RPI, with 2xSX125x and some SAW filter.
Testing is fine, and I just sended out to PCBA factory, maybe sold some unit on tindle later this year.
The newer version sch&layout will upload later this month.

Closed 2017-12-06.

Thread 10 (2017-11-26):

Unreliable during heavy load

will127534, 2017-11-26:
Setup:
one RF98 Transmitter @ 432Mhz, transmitting 6-axis data (24byte+2byte header) per 100ms
one RPI-Gateway with full channel on

If I tested indoor, Gateway will output some error data, the full log is here
[Log](https://asciinema.org/a/72G7waVnfnynvr8EB0Rmi2gFS)
it seems that SX1301 will output some wrong data.

But I when I try it near the window(with some wind), the error goes away, so I believed that it is cause by thermal problem, maybe do some measurement later.

I've already added a heatsink on top of SX1301, but it seems not enough....

apparell, 2018-03-08:
Hello, first of all congrats for the project.
I'm an energy engineering working in an heat-sink company. Maybe I can help you.
if did you record high temp, Can you post some value?

If the problem if thermal, we can design together an enclosure w/ embed heat-sink and ventilation.
let me know.
regards,
apparell

Brat0x2, 2018-07-14:
@will127534 Hi!
I've got the the board version 3 (2018/03/28). I noticed that sx1308 is very hot (can't touche my finger)! Is it normal working conditions?
There is no any heatsink on sx1308, the board powered from Raspberry Pi over 40pin connector, uUSB power source 5V, 2A.

will127534, 2018-07-14:
@Brat0x2
Yes it is, SX1308 consume about 0.6A, which means it takes about 1W
I did measure about 55~60 Degrees on the SX1308, barely touchable...

will127534, 2018-07-14:
@Brat0x2
Depend on where if works, I have an indoor one without any heat sink and it works just fine,
But for my outdoor one, I did added a fan to cool two gateway in a box under the sun.

mikini, 2018-07-30:
You need to ensure proper transfer of thermal energy from both top (heat sink) and bottom (solder to PCB plane with substantial copper area 3 exposed to air) of the chip. To operate within the 0-70 deg. C operating conditions of the datasheet Semtech specifies 100 cm2 copper below and heatsink on top.

Let me quote from the datasheet:

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

Source: [SX1308 Datasheet, paragraph 2](https://www.semtech.com/uploads/documents/sx1308.pdf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)

And from the thermal application note:

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

Source: [SX1308 Thermal Dissipation: Technical Analysis and Recommendations, paragraph 3](https://www.semtech.com/uploads/documents/SX1308_PicoCell_GW_Thermal_Dissipation_Technical_Analysis_V1.0.pdf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)

will127534, 2018-08-05:
@mikini  That is a really useful data!
It seems that two Aluminum Heat Sink for Raspberry Pi (top and bottom) is good enough for heat dissipation. I think RPi Gateway V3 is larger than their PicoCell gateway, so using the same setup will perform better.

From the measurement on "RPIZero" Gateway V3(not released yet), I measured about 50~55 degrees with a large heatsink and 60 degrees without, which is better than PicoCell GW without housing and with heat sink. Although I didn't run for 24 Hours, only for couple hours.

Anyways, I'll do a experiment on RPI Gateway V3 later.

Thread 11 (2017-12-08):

SX1301 VS SX1308?

adz1122, 2017-12-08:
I would like to ask, what is the difference SX1301 and SX1308?
think you!

will127534, 2017-12-08:
In terms of function: No, SX1301 is same as SX1308, pin-to-pin and software compatible
But, SX1301 has -142.5 dBm sensitivity, SX1301 only have -139 dBm.

adz1122, 2017-12-08:
thinks，“But, SX1301 has -142.5 dBm sensitivity, SX1301 only have -139 dBm.”SX1301 only have -139 dBm?

will127534, 2017-12-08:
Sorry typo
Should be SX1301 has -142.5 dBm sensitivity, SX1308 only have -139 dBm.

adz1122, 2017-12-08:
thinks you， Are you doing your own gateway? I am also very interested in this, add a WeChat?
My WeChat：17512020988
I am from ShenZhen An electronic enthusiast

will127534, 2017-12-09:
Yes, I am building by own gateway.
Shenzhen is a perfect place to be electronic enthusiast, too bad that I don't have WeChat though...
如果可以講中文的話就直接打中文好了 :D

adz1122, 2017-12-09:
好的，以后多交流，你开发这个网关准备用在哪里呢，我很想用LORAWAN做些传感器用在农业上，不过我没玩过树莓派，只玩过arduino或者STM32了。

will127534, 2017-12-09:
最主要應該是用在探空儀(High Altitude Balloon)，其他的話應該就小範圍的感應器網路了，類似你說的農業用途，不過收的應該是氣體感應器與PM2.5的資料
STM32應該也能玩網關，Semtech有一個[picoGW](https://github.com/Lora-net/picoGW_mcu)
雖然picoGW還需要用電腦，但是STM32<->SX1301的HAL都在那邊，應該可以做一個獨立的網關
我有看到一些掏寶上的店家在做AT-cmd的Gateway，我猜應該是拿picoGW改的

Serjaru, 2018-10-05:
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

Can find 17512020988

bkrajendra, 2019-11-18:
Hi all Im also doing my own gateway.

goodmasher, 2020-04-21:
寡人是做射频硬件的，对于SX1257/SX1255 与 SX1301构成的网关，如何进工厂生产的测试一直找不到方法。希望大家在软件上能整个生产测试的方法。否则很难量产。

Closed 2018-05-26.

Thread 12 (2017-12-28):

GPS selection

Kiogora, 2017-12-28:
Hi,

Great work you have done so far. I also wanted to try to create a gateway myself then I stumbled on your project. I have gone through the LoRaGW userspace C code and currently they use the Ublox GPS sensors as it outputs raw GPS time, not UTC. I have not yet confirmed what the GPS time is used for but your project has motivated me to check up on it later today. Do you have info on this?

As to my questions:

1. I have some Quectel L96 and L80 parts and the most they do is give UTC time. Did you have to change the codebase to accept the quectel version NMEA strings?
2. Any plans to do a PoE version? That would be something interesting and would be willing to look into.

will127534, 2017-12-28:
Hi Kiogora,
Answering the first one: No, I replace GPS module to MAX-7Q, see #5
Second one: Yes, I'm actually deploying some gateway in the wild, and find out that I really need POE to simplify wiring, building PoE sink board is definitely is on my todo list.
But I won't build PoE with this board, there is not much space for isolated dc-dc and a large PoE RJ45 connector. Two plans here, one is to build a new POE shield for RPI, the other one is using computer module or other SBC module like MT7688 to build a PoE capable RPI-like board or single board with SX1301. I'm still finding easier PoE solution to give it a try, before then, I'll use commercial PoE injector/isolator to power RPI Gateway.

Thanks for the compliment!

Kiogora, 2017-12-30:
Thanks for the quick reply and clarification on the GPS chip.

I will go for an off the shelf solution also, for now as I chalk up a new design of a concentrator controller using the ESP32.It should be quick to port and test. I notice that you had two issues with your testing:
1. PLL lock and supposedly thermal issues. As a suggestion: You could try adding more via spaced at lambda/20 to the design to reduce the inductance on the board, especially near the RF sections that connects the ground planes. It may solve unforseen problems.

piratfm, 2019-04-05:
With such a small patch, it's possible to use ATGM336H-5N11 cheap GPS-module, which is also supports UBX messages format, required by the gateway. The only requirement - is not to connect pin 7 (NC) to the power line.

```
diff --git a/libloragw/src/loragw_gps.c b/libloragw/src/loragw_gps.c
index c0e0ded..3fd40de 100644
--- a/libloragw/src/loragw_gps.c
+++ b/libloragw/src/loragw_gps.c
@@ -529,13 +529,14 @@ enum gps_msg lgw_parse_nmea(const char *serial_buff, int buff_size) {
     } else if (match_label(serial_buff, "$G?RMC", 6, '?')) {
         /*
         NMEA sentence format: $xxRMC,time,status,lat,NS,long,EW,spd,cog,date,mv,mvEW,posMode*cs<CR><LF>
-        Valid fix: $GPRMC,083559.34,A,4717.11437,N,00833.91522,E,0.004,77.52,091202,,,A*00
+        Valid fix: $GPRMC,083559.34, A,4717.11437,N,00833.91522,E,0.004,77.52, 091202,,,A*00
+                   $GPRMC,083559.34, A,4717.11437,N,00833.91522,E,0.004,77.52, 091202,,,A,V*11
         No fix: $GPRMC,,V,,,,,,,,,,N*00
         */
         memcpy(parser_buf, serial_buff, buff_size);
         parser_buf[buff_size] = '\0';
         nb_fields = str_chop(parser_buf, buff_size, ',', str_index, ARRAY_SIZE(str_index));
-        if (nb_fields != 13) {
+        if (nb_fields < 13 || nb_fields > 14) {
             DEBUG_MSG("Warning: invalid RMC sentence (number of fields)\n");
             return IGNORED;
         }

```

mikini, 2019-04-05:
Nice, haven't seen the ATGM336H GNSS module before.

It's supposedly [LEA](http://www.icofchina.com/d/file/xiazai/2016-12-05/b5c57074f4b1fcc62ba8c7868548d18a.pdf#page=3) (possibly even [NEO and MAX](https://www.electrodragon.com/product/gnss-module-atgm336h/)) series compatible, but if your experience failing NMEA output that seems odd. Unless the loragw parser is more restrictive than the NMEA protocol dictates. It is also my previous impression that the GPS time from the UBX protocol was important. Have you verified how it behaves when [parsing the UBX-NAV-TIMEGPS packet](https://github.com/Lora-net/lora_gateway/blob/master/libloragw/src/loragw_gps.c#L441).

Just dumping some info here;

$9 on Tindie; https://www.tindie.com/products/ICStation/atgm336h-gps-bds-gnss-positioning-module12420/

On VoltLog; https://youtu.be/pfpyvJWgOqM?t=418 (warns of differing constellation support of different chip variants)

User Manual; http://www.icofchina.com/d/file/xiazai/2016-12-05/b5c57074f4b1fcc62ba8c7868548d18a.pdf

It seems to be based on the generic GNSS chipset [AT6558](http://www.icofchina.com/pro/dingwei/2016-07-29/5.html#), datasheet; http://www.icofchina.com/d/file/xiazai/2016-12-05/b1be6f481cdf9d773b963ab30a2d11d8.pdf

Info on some Western sites here:
https://www.robotics.org.za/NEO-M8N-MOD
https://www.electrodragon.com/product/gnss-module-atgm336h/

piratfm, 2019-04-05:
Here is sample of log of `./test_loragw_gps`:

```
Note: parsing UBX frame> b5 62 01 20 10 00 58 e1 b4 1b f6 ff ff ff ff 07 12 07 38 00 00 00 83 7c 24 47

~~ UBX NAV-TIMEGPS sentence, triggering synchronization attempt ~~
    * Synchronization successful *
    UTC reference time: 1554455221.000000000
    GPS reference time: 1238490438.999999989
    Internal counter reference value: 5946088
    Clock error: 1.000000000
    * Test of timestamp counter <-> GPS value conversion *
    Test value: 6446088
    Conversion to GPS: 1238490439.499999989
    Converted back: 6446088 ==> 0µs
    * Test of timestamp counter <-> UTC value conversion *
    Test value: 6446088
    Conversion to UTC: 1554455221.500000000
    Converted back: 6446088 ==> 0µs

```

The gateway periodically (once per 30s) showing such info:
```
INFO: Disabling GPS mode for concentrator's counter...
INFO: host/sx1301 time offset=(1554455463s:612158µs) - drift=-3µs
INFO: Enabling GPS mode for concentrator's counter.
```
Also it's still giving me some warnings about out-of-sync sometimes, after long time of work, but that might be bad TXCO.

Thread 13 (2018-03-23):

BOM and 868 mhz

karthirockz, 2018-03-23:
Hi Congrats and thanks for making it open source.

1. Can you please share the BOM file (bill of materials)

2. Please update LoRa-concentrator/Version2/RPI/SCH.pdf some of the labels of components are overlapped

3. What is the procedure to change it to 868 mhz

apparell, 2018-04-04:
To change the operational frequency you have to adapt passive RF components and SAW filter from the radio frequency front end. Ther's lot of resources on the web about sizing RF matching network also.
Regards!

apparell, 2018-04-04:
When Will will (WWW :D) publish the V3, I can help you to make 868 version. enjoy and happy open project!

clodpi, 2018-04-04:
@will127534 thanks, waiting for your 868 version

karthirockz, 2018-04-04:
@will127534 thanks, waiting for your 868 version

davidfungf, 2018-05-14:
Hi @will127534 , waiting for your 868 version too. Thanks.

gadLinux, 2018-06-19:
Me too. I suppose it's not as easy as change the parts you told above

Closed 2018-05-26.

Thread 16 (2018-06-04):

Can this module do LBT ? Listen before talk ?

4mig4, 2018-06-04:
It seems that HAL from SEMTECH supports LBT when version is > = 4.1.0, but can AS923 be supported by your board ? (Japan)

will127534, 2018-06-04:
No, it won't support LBT since it needs a FPGA + SX1278 to scan the channel for LBT.

Note that if anyone have the ref V1.5 design sch, I'm willing to add LBT support. 😄

4mig4, 2018-07-15:
Ok thanks and no I do not have the reference design v1.5

will127534, 2018-08-31:
Reopen this issue because it is on my todo list...

piratfm, 2019-03-20:
Schematic can be reversed from this photos: https://fccid.io/AU792U13A16859/Internal-Photos/Internal-Photos-3321124

will127534, 2019-03-20:
Almost, but you can't, because it is a multi layer board.
I'm hoping to reverse by reversing the FPGA bitstream, but I can't read verilog......

piratfm, 2019-03-21:
Yep, You are right, but on this one:
http://www.embit.eu/wp-content/uploads/fronte-retro1.png
The signal layers are top/bottom and inner - are powers. So this is good suggestion to start. Also There is correct FPGA (iCE40LP1K-CM49) to which firmware is avaliable.

4mig4, 2019-03-21:
Very to see to that you think it is a worthy thing to do.

piratfm, 2019-03-22:
Pin mapping of FPGA, correct me if I'm wrong:
```
#SPI interface to HOST
set_io SPI_MISO      A5
set_io SPI_CS        A6
set_io SPI_SCLK      A3 #Wire shared with SX1301_SCLK and EEPROM_SCLK
set_io SPI_MOSI      A4 #Wire shared with SX1301_MOSI and EEPROM_MOSI

#SPI slave 0:
set_io SX1301_GPIO1      D7
set_io SX1301_GPIO3      A2
set_io SX1301_GPIO4      B2
set_io SX1301_CSN        B3
set_io SX1301_MISO       B4
set_io SX1301_RADIO_RST  F4 #this is input, not used in FPGA fw

#SPI slave 1: FPGA itselve

#SPI slave 2:
set_io EEPROM_CSN    A7
set_io EEPROM_MISO   C4

#SPI slave 3:
set_io SX1272_MOSI   A1
set_io SX1272_NSS    E2
set_io SX1272_MISO   D2
set_io SX1272_SCK    D3
set_io SX1272_RESET  F2

#Stays in the middle between I2S interface of SX1301 and SX125X (radio A)
set_io A_SP_CLK_IN   D1
set_io A_QI_TX_IN    B1
set_io A_IQ_TX_IN    C1

set_io A_SP_CLK_OUT  F3
set_io A_IQ_TX_OUT   G3
set_io A_QI_TX_OUT   G4
```
There is some small microchip SPI eeprom, but it's not used in software.
FPGA can be replaced by more DIY-friendly with QFN48 package, like ICE5LP1K-SG48. Only pin map file must be changed (and recompile firmware with icestorm). Also SX1272 share reference clock with SX125X and receiving RF just after second SAW (have no idea about how impedance matching has been made there). Maybe I can try to it with my lattice ICE40UP5K dev board later... But first need to solder (finalize) my gateway.

will127534, 2019-03-23:
@piratfm
That was awesome!
I'm recently doing other projects that uses ICE5LP1K-SG48 (a.k.a learning verilog), so I also have some chip and boards :D
I'm glad that I left a bunch of resistor between the SPI lines, it makes it easier to modify.
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

jgriessen, 2019-08-16:
Hi,
I have customers that want LoRa gateways.  I wonder if you are available to make some V3 boards
to sell me on tindie and coach me for pay on setup of all the software to connect to lorawan thethingsnetwork?  Later, we can make improved boards, weather enclosures, etc.  Interested?  Are you trained with a BSEE degree, or hobby?  Thanks, John

PostScript:  I knew some verilog for chip design, but have forgotten most of it.  Listen before talk would be a fine feature to brag about!

symdeb, 2019-10-22:
Hope Will would (re)consider to build another batch of boards. After surveying what is low cost and available right now, Lora, in low cost form, is still not so accessible, not much  choice and this looks to be the best solution so far.  RAK(831) boards are not cheap either. Trying to build an IoT gateway (not using RPI but with STM32/NXP based embedded with SPI) and would like to add in Lora. What would be nice are small companion device development ("thing") boards to connect sensors and actuators for prototype solution  purposes.  I am in Taipei City as well.

jgriessen, 2019-11-15:
@symdeb  How is your project to build IoT gateway with STM32/NXP parts coming?  Do you use pcb-rnd to make boards?  Maybe we can collaborate to get a low cost gateway and sensor boards?  I've done work with TinyOS on sensor boards, but that OS stalled.  RIOT is the OS I am interested in now.

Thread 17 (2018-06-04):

Combining RX paths

amateusz, 2018-06-04:
I'm not a RF design expert, but shouldn't RF RX paths (N$49 at your schematic for v3) be merged using some impedance matching ? Integrated [resistor divider](http://www.radio-electronics.com/info/rf-technology-design/coupler-combiner-splitter/rf-resistive-splitter-combiner-divider.php) (losses >= 6dB) or Wilkinson divider (losses >= 3dB). They cost pennies (~$0.3).

will127534, 2018-06-04:
There is two inductor L1 and L2 and two Cap C22 with C20 for impedance matching.

Closed 2018-06-04.

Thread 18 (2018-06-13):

one antenna

EduardShaid, 2018-06-13:
What is the reason that you switched from four antennas in version 1, to one antenna in version 3?

will127534, 2018-06-13:
The first version is just want to make sure SX1301 & SX1255 is working, so to keeping everything simple, every RF path is straight from IC to SMA connector.

After I successfully boot up SX1301,  the 2nd is aimed for 8-ch receiver, so I combine the both RX and
ditch one Tx of SX125Xs, so two RF left, one TX one RX.

After the 8-ch receiver project is finished, there is some people asking for LoRawan support.
So to simplify the setup, I moved to single antenna, which combine RX/TX with RF switch and it is the current version.

EduardShaid, 2018-06-19:
Thanks for the answer, but there are still questions:

1) The project design does not include the names of TXCO. Are there any requirements for their characteristics, such as accuracy or stability?
2) What were the requirements for the motherboard material or did the conventional FR-4 take it for the board?

will127534, 2018-06-19:
1.  I'm stick with Microchip Reference Design's NT3225SA, but I think any TCXO will do the job.
2. 4-Layer FR4 for version 3, I need more layers to maintain solid ground plane with RF frontends.

EduardShaid, 2018-06-19:
Thanks.

Closed 2018-06-13.

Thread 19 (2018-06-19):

TXCO

EduardShaid, 2018-06-19:
There are still questions:

1. The project design does not include the names of TXCO. Are there any requirements for their characteristics, such as accuracy or stability?
2. What were the requirements for the motherboard material or did the conventional FR-4 take it for the board?

Thanks.

bkrajendra, 2019-11-18:
i have also asked same question at https://github.com/will127534/LoRa-concentrator/issues/38#issuecomment-552165267
But still waiting for reply from @will127534

will127534, 2019-11-18:
1.The main 133Mhz Osc doen't have a strict requirement, but the 32Mhz do, since it is the clock for RF components, the reference design uses 2725T series.
2.FR-4 will do the work.

Closed 2019-11-18.

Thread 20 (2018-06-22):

433Mhz和470Mhz频率，需要做哪些改进？

komoya, 2018-06-22:
你好!
433Mhz 和470Mhz，除了把SX1257换成SX1255，还需要对哪些元件进行更换呢？  麻烦指教。

will127534, 2018-06-22:
還有Balan要換成433Mhz的版本，PA和LNA的周邊匹配也要換一下，不過應該都有在PA/LNA的Datasheet
另外還有三個SAW filter+Low Pass Filter要換...
打字打到這邊我覺得基本上RF Frontend就只有IC沒換，其他都要...

Closed 2018-07-31.

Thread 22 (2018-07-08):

"failed to start the concentrator"

Zytheran, 2018-07-08:
I managed to get the system running and ran it say 5 times with no errors and was about to work out why the connection was not showing on the Things network when I got the error message "failed to start the concentrator".
command run was
./lora_pkt_fwd > logfile.txt

Is there a list of things to check? It seems odd that is was working one minute and not the next. [The only thing I did was shut it down to swap over the power supply for the Raspberry Pi because I was getting low voltage warnings, which in itself was a bit odd because the voltage was 5.1V and it was a 2A supply providing 300mA. Anyhow swapped PS. I wasn't sure this was a Raspberry Pi voltage error and not one from the LoPoWAN board?]
Is there a list of things to check with the LoPoWAN setup, everything was done as per the instructions.
Up to the end of the TTN network setup guide.
log file is as follows:
*** Beacon Packet Forwarder for Lora Gateway ***
Version: 4.0.1
*** Lora concentrator HAL library version info ***
Version: 5.0.1;
***
INFO: Little endian host
INFO: found global configuration file global_conf.json, parsing it
INFO: global_conf.json does contain a JSON object named SX1301_conf, parsing SX1301 parameters
INFO: lorawan_public 1, clksrc 1
INFO: no configuration for LBT
INFO: antenna_gain 0 dBi
INFO: Configuring TX LUT with 16 indexes
INFO: radio 0 enabled (type SX1257), center frequency 917200000, RSSI offset -166.000000, tx enabled 1, tx_notch_freq 0
INFO: radio 1 enabled (type SX1257), center frequency 917900000, RSSI offset -166.000000, tx enabled 0, tx_notch_freq 0
INFO: Lora multi-SF channel 0>  radio 0, IF -400000 Hz, 125 kHz bw, SF 7 to 12
INFO: Lora multi-SF channel 1>  radio 0, IF -200000 Hz, 125 kHz bw, SF 7 to 12
INFO: Lora multi-SF channel 2>  radio 0, IF 0 Hz, 125 kHz bw, SF 7 to 12
INFO: Lora multi-SF channel 3>  radio 0, IF 200000 Hz, 125 kHz bw, SF 7 to 12
INFO: Lora multi-SF channel 4>  radio 1, IF -300000 Hz, 125 kHz bw, SF 7 to 12
INFO: Lora multi-SF channel 5>  radio 1, IF -100000 Hz, 125 kHz bw, SF 7 to 12
INFO: Lora multi-SF channel 6>  radio 1, IF 100000 Hz, 125 kHz bw, SF 7 to 12
INFO: Lora multi-SF channel 7>  radio 1, IF 300000 Hz, 125 kHz bw, SF 7 to 12
INFO: Lora std channel> radio 0, IF 300000 Hz, 500000 Hz bw, SF 8
INFO: FSK channel 8 disabled
INFO: global_conf.json does contain a JSON object named gateway_conf, parsing gateway parameters
INFO: server hostname or IP address is configured to "router.au.thethings.network"
INFO: upstream port is configured to "1700"
INFO: downstream port is configured to "1700"
INFO: packets received with a valid CRC will be forwarded
INFO: packets received with a CRC error will NOT be forwarded
INFO: packets received with no CRC will NOT be forwarded
INFO: GPS serial port path is configured to "/dev/serial0"
INFO: found local configuration file local_conf.json, parsing it
INFO: redefined parameters will overwrite global parameters
INFO: local_conf.json does not contain a JSON object named SX1301_conf
INFO: local_conf.json does contain a JSON object named gateway_conf, parsing gateway parameters
INFO: gateway MAC address is configured to B827EBFFFEE3F5F6
INFO: packets received with a valid CRC will be forwarded
INFO: packets received with a CRC error will NOT be forwarded
INFO: packets received with no CRC will NOT be forwarded
INFO: [main] TTY port /dev/serial0 open for GPS synchronization
ERROR: [main] failed to start the concentrator
-----------------------------------------------
Unfortunately I don't have a log from when it used to run but I know it was quite a few more lines, the GPS went on and off and then it was doing a few push commands or something.
json files attached.

[global_conf.json.txt](https://github.com/will127534/LoRa-concentrator/files/2174222/global_conf.json.txt)
[local_conf.json.txt](https://github.com/will127534/LoRa-concentrator/files/2174223/local_conf.json.txt)

Zytheran, 2018-07-10:
Solution was to go back into the lora_gateway directory
cd ./lora_gateway/

and then start the gateway again.

Start gateway by:
./reset_lgw.sh start

and then get back onto TTN via
cd ./lora_pkt_fwd
./lora_pkt_fwd

...and all good!

As mentioned in the opening post, this issue didn't always occur after power cycle however in the headless setup when the RPi is up a pole on the roof I'll be setting up a script to start the Gateway each time it boots before the LoRa packet forwarder starts.
(BTW issue with the noshow on TTN was because you need to configure the Gateway with the "Legacy packet forwarder" option when setting up a new Gateway)

will127534, 2018-07-10:
Hi Zytheran,
Yes, you should restart the gateway every power cycle to ensure SX1308 is in the init state.
I'll update the guide for clarify, thanks 👍

Closed 2018-07-10.

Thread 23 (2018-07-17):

GPS coordinates

Brat0x2, 2018-07-17:
@will127534 Hi!
I use GPS on the board version 3 with external antenna.
I see log messages:
`### [GPS] ###`
`# Valid time reference (age: 0 sec)`
`# no valid GPS coordinates available yet`
`##### END #####`
There is no valid coordinates for a long time. Why I didn't see them at all?

will127534, 2018-07-17:
Hi @Brat0x2
It seems GPS cannot fetch enough signal for solving the location (but still able to output time reference)
Can you confirm the GPS antenna can get a good reception?

Also you can use
`screen /dev/serial0 9600`
to see the NEMA output from GPS, which have some info about the signal strength.

Brat0x2, 2018-07-17:
@will127534
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

will127534, 2018-07-17:
Yeah... It seems gps only lock  1 sat, where did you put the antenna?

Brat0x2, 2018-07-17:
@will127534 Simple external antenna with 2 meters cable, on the window to the North.

will127534, 2018-07-17:
It is active or passive antenna?
if active, 5V or 3.3V?
The GPS Antenna port will output 3.3V to active antenna, so if you were using 5v active antenna,
it may cause the problem.

Brat0x2, 2018-07-17:
@will127534 It is active GPS antenna, 2.7...5.0V

will127534, 2018-07-17:
hmm.... can you put the antenna outdoor?

Brat0x2, 2018-07-17:
There is no possibility now. I'll try as I can. Thanks for your help!

Brat0x2, 2018-08-30:
@heitorPB the problem has been solved. GPS depends on our local weather.

Closed 2019-11-18.

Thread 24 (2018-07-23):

Frequency Plan

hssounamed, 2018-07-23:
hi will
when i bot the SX1308 Raspberry Pi Lora Gateway i have chosen the 868 MHz, i wanted to ask if by simple changing the Antenna to 915 Mhz will it be possible to use it as a Lora concentrator with a frequency plan of 915 MHz after configuring the global_conf files to 915 MHz.

if that's not possible you mentioned that the difference between the 868 model and the 915 model is simply 4 filters that we need to change, so is it possible to share the BOM file for the 868 MHz.
thank you have a great week.

Closed 2018-07-26.

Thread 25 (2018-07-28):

Capacitator values

deep470, 2018-07-28:
Capacitators have voltage ratings, e.g. 5v, 10v, 25v, 50v.*

Which one do you recommend? Is 16v enough or better 25v to be sure?

Also: M15 (CAP-0402) has a value of 1K? Is that a special capacitor?

1nF = 1000pF so M5, M17 and C19, C34 are the same, right?
C3 is the same as C1, C23, C24, C35?

Sorry, my electronics knowledge hasn't been used for decades.
Thank you for your great work!

will127534, 2018-07-31:
So I normally double the voltage it handles,
for 3.3V rail => 10V or 6.3V
     1.8V => 6.3V
     5V => 10V
For the NP0 on the RF path and other small caps, their voltage rating is more then enough.

For M15, the package/sch name may cause some confusion, it is a 1K resistor, the M prefix is for impendence, so the component might be L,R or C, depends on the frequency needed.

M5,M17 should be 1500pF not 1000pF, so it is different then C19/C34
And C3 is the same as C1, C23, C24, C35

Thank you for the compliment! 👍

Closed 2018-07-31.

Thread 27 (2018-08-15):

Using LoRa-concentrator V2 on spi 0.1

hamersin, 2018-08-15:
JP1 allows selecting between SPI 0.0 and SPI 0.1. If I wanted to use SPI 0.1, what do I have to update to have the raspberry PI see the concentrator?

will127534, 2018-08-16:
You will need to change /libloragw/src/loragw_spi.native.c line 57
from /dev/spidev0.0 to /dev/spidev0.1
then recompile again.

hamersin, 2018-08-17:
Thank worked - Thanks

Closed 2018-08-17.

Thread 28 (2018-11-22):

One of sx1257 has very low RSSI

Brat0x2, 2018-11-22:
I've got the LoRa-concentrator (the board version 3), EU868 configuration.
My LoRaWAN-mote sends messages, radio0 (ch0, ch1, ch2) receives them with RSSI -27, but radio1 (ch3, ch4, ch5, ch6, ch7) receives them corrupted only on ch5 with RSSI -111.
Thus only 3 from 10 messages reaches my server.
Is it a hardware problem? Maybe the board is damaged?

will127534, 2018-11-23:
Yes, it seems to be a problem of the receiver,
and it seems that Radio B has a problem receiving the data...
Please contact me via tindle to send a replacement.

will127534, 2018-11-27:
Note: I think the problem is the SX1257 on Radio B.

Brat0x2, 2018-11-27:
@will127534 ok, thanks

Closed 2018-11-27.

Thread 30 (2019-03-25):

Component values

SG-O, 2019-03-25:
Thanks for your great design!

I'm currently picking all the parts to build my own full size V3. I have a few questions about some of the components:

L7 has a value of 8.2uH in a 0402 package. Is this really correct?
C21 is EOL and no longer available. Can I choose a different part? What are the requirements for the component?

Could you provide me with the components you use for botch oscillators? I have a hard time picking a correct model.

Thanks!

will127534, 2019-03-25:
L7 should be 8.2nH, I'll fix that typo, thanks!

C21 is decouple cap for GPS antenna power, so it is fine to replace with other similar cap,
just pick NP0 and it will be fine, the voltage rating for 47pF will be more than enough but just make sure it is larger than 6.3V

NT3225SA for 32Mhz TCXO
2725T for 133Mhz XO

will127534, 2019-04-05:
Yeah.. I think that's a little bit overkill, maybe replacing it with 100ohm will be fine.

piratfm, 2019-04-05:
The problem - is that SX1301 don't see SX125X chips on SPI bus at all with that loarge resistors. I replaced them to 0R and gateway starts working as expected.

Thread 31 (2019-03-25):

Replacement for the GPS receiver

SG-O, 2019-03-25:
Would it be possible to replace the Max-7Q with the pin compatible Quectel L70. It outputs a  100ms 1 PPS signal but only supports NMEA output.
This would significantly reduce the price (5$ vs 25$)

will127534, 2019-03-25:
Refer to issue #5
I did used Quectel L70 and L85 before, but I realize that the software is using uBlox's UBX protocol.
Max-7Q doesn't cost that much though.... there are a lot of module factory uses uBlox chipset to make compatible "Max-7Q"

mikini, 2019-03-25:
When I looked into this 1.5 years ago the software exclusively supported the ublox specific UBX protocol, see #5 (and similar question in #12). Don't know if that is still the case, however.

Closed 2019-03-25.

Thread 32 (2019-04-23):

File Error

Cynicroute, 2019-04-23:
Getting `line 8, column 16: This is not an EAGLE file.` error with Radio_RPIv15_915.sch

mikini, 2019-04-23:
Maybe it would be a good idea to specify exactly in what software, version and computing environment you are attempting to open which edition of the file?

The only Radio_RPIv15_915.sch I can find in the current master branch seems to be generated by Eagle 8.4.3:

```
$ find LoRa-concentrator/ -name Radio_RPIv15_915.sch
LoRa-concentrator/Version3/RPI/Radio_RPIv15_915.sch
$ grep -r eagle LoRa-concentrator/Version3/RPI/Radio_RPIv15_915.sch
<!DOCTYPE eagle SYSTEM "eagle.dtd">
<eagle version="8.4.3">
</eagle>
$
```
I don't know about Eagle or its file formats but line 8, char 16 in that file doesn't seem to contain anything suspicious.
```
$ head -8 LoRa-concentrator/Version3/RPI/Radio_RPIv15_915.sch |tail -1
<setting verticaltext="up"/>

$
```

Trying to import the Radio_RPIv15_915.sch and brd into KiCad 5.1 (File->Import Project->EAGLE CAD...) on Ubuntu 16.04 succeeds without any apparent issues (apart from some layer warning in brd) so I suspect the file must be ok.

Cynicroute, 2019-04-24:
Accessing /Version3/RPI/Radio_RPIv15_915.sch on Windows 10 Education, Build 17134.706 Version 1803. Using EAGLE 9.1.3 Education.

Indeed, there's nothing of note at L8,C16. Curious. A Google search did find other similar incidents with the same error. What worked for me was to unzip the entire branch and manually replace the .brd and .sch files with the stand-alone versions in the directory.

will127534, 2019-04-24:
I just download the file using right click on the "raw button"
and opened using EAGLE 9.1.1 on windows 10 1803, doesn't seems to have any problem though.

Cynicroute, 2019-04-24:
Must be something with my EAGLE build... I'll patch and update.

Closed 2019-11-18.

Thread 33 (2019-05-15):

Concentrator failed to start error

kungfupizza, 2019-05-15:
Hi,
I am having this error as shown below from a long time. It got solved once when a good power supply was provided but having it again. I always do the reset as told.
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

navinyate, 2019-05-15:
What is amps which u supplying to gateway. It should be atleast 2A

navinyate, 2019-05-15:
And check if there are any loose wires.

himitu23, 2019-05-15:
I also have this problem. I have searched several solution on some QAs, however I couldn't solve.

navinyate, 2019-05-15:
what kind of problem.

will127534, 2019-05-15:
LoRa Gateway is pretty sensitive to the power supply (normally talking to peak power consumption)
So make sure the power supply is working Ok.

navinyate, 2019-05-15:
Which is gateway ur using

himitu23, 2019-05-15:
> LoRa Gateway is pretty sensitive to the power supply (normally talking to peak power consumption)
> So make sure the power supply is working Ok.

OK, Thanks, I will try to use 2.5A supply

Closed 2019-06-03.

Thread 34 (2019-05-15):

loragw_pkt_logger: ERROR: failed to start the concentrator

himitu23, 2019-05-15:
I have an error similar to that; https://github.com/will127534/LoRa-concentrator/issues/33

I have Version 3 of LoRa Concentrator, this is so good Gateway for using LoRaWAN with TheThingsNetwork for PoC.
I examined this on RPi3(Latest Raspbian Desktop), however it doesn't run successfully.

We can found this wiki; https://github.com/will127534/LoRa-concentrator/wiki/Startup-Guide
I got below error at first step(2.5A supplied);

pi@ttn-gateway:~/lora_gateway/util_pkt_logger $ sudo ./util_pkt_logger
loragw_pkt_logger: INFO: found global configuration file global_conf.json, trying to parse it
loragw_pkt_logger: INFO: global_conf.json does contain a JSON object named SX1301_conf, parsing SX1301 parameters
loragw_pkt_logger: INFO: lorawan_public 1, clksrc 1
loragw_pkt_logger: INFO: radio 0 enabled (type SX1257), center frequency 915000000, RSSI offset -166.000000, tx enabled 0, tx_notch_freq 0
loragw_pkt_logger: INFO: radio 1 enabled (type SX1257), center frequency 916500000, RSSI offset -166.000000, tx enabled 0, tx_notch_freq 0
loragw_pkt_logger: INFO: LoRa multi-SF channel 0 enabled, radio 1 selected, IF -400000 Hz, 125 kHz bandwidth, SF 7 to 12
loragw_pkt_logger: INFO: LoRa multi-SF channel 1 enabled, radio 1 selected, IF -200000 Hz, 125 kHz bandwidth, SF 7 to 12
loragw_pkt_logger: INFO: LoRa multi-SF channel 2 enabled, radio 1 selected, IF 0 Hz, 125 kHz bandwidth, SF 7 to 12
loragw_pkt_logger: INFO: LoRa multi-SF channel 3 enabled, radio 0 selected, IF -400000 Hz, 125 kHz bandwidth, SF 7 to 12
loragw_pkt_logger: INFO: LoRa multi-SF channel 4 enabled, radio 0 selected, IF -200000 Hz, 125 kHz bandwidth, SF 7 to 12
loragw_pkt_logger: INFO: LoRa multi-SF channel 5 enabled, radio 0 selected, IF 0 Hz, 125 kHz bandwidth, SF 7 to 12
loragw_pkt_logger: INFO: LoRa multi-SF channel 6 enabled, radio 0 selected, IF 200000 Hz, 125 kHz bandwidth, SF 7 to 12
loragw_pkt_logger: INFO: LoRa multi-SF channel 7 enabled, radio 0 selected, IF 400000 Hz, 125 kHz bandwidth, SF 7 to 12
loragw_pkt_logger: INFO: LoRa standard channel enabled, radio 1 selected, IF -200000 Hz, 250000 Hz bandwidth, SF 7
loragw_pkt_logger: INFO: FSK channel enabled, radio 1 selected, IF 300000 Hz, 125000 Hz bandwidth, 50000 bps datarate
loragw_pkt_logger: INFO: global_conf.json does contain a JSON object named gateway_conf, parsing gateway parameters
loragw_pkt_logger: INFO: gateway MAC address is configured to AA555A0000000000
loragw_pkt_logger: INFO: found local configuration file local_conf.json, trying to parse it
loragw_pkt_logger: INFO: local_conf.json does not contain a JSON object named SX1301_conf
loragw_pkt_logger: INFO: local_conf.json does contain a JSON object named gateway_conf, parsing gateway parameters
loragw_pkt_logger: INFO: gateway MAC address is configured to AA555A0000000101
loragw_pkt_logger: ERROR: failed to start the concentrator

Who do know or can solve this?

will127534, 2019-05-15:
Ok, then try open the debug output to see where is the problem
to open the debug config, modify the following file: lora_gateway/libloragw/library.cfg
change DEBUG_HAL= 0 to DEBUG_HAL= 1
then recompile both packet_forwarder and lora_gateway and try running the gateway again.

himitu23, 2019-05-15:
Thanks for replying.

I got below;

pi@ttn-gateway:~/lora_gateway/util_pkt_logger $ ./util_pkt_logger
loragw_pkt_logger: INFO: found global configuration file global_conf.json, trying to parse it
loragw_pkt_logger: INFO: global_conf.json does contain a JSON object named SX1301_conf, parsing SX1301 parameters
loragw_pkt_logger: INFO: lorawan_public 1, clksrc 1
lgw_board_setconf:427: Note: board configuration; lorawan_public:1, clksrc:1
loragw_pkt_logger: INFO: radio 0 enabled (type SX1257), center frequency 915000000, RSSI offset -166.000000, tx enabled 0, tx_notch_freq 0
lgw_rxrf_setconf:488: Note: rf_chain 0 configuration; en:1 freq:915000000 rssi_offset:-166.000000 radio_type:2 tx_enable:0 tx_notch_freq:0
loragw_pkt_logger: INFO: radio 1 enabled (type SX1257), center frequency 916500000, RSSI offset -166.000000, tx enabled 0, tx_notch_freq 0
lgw_rxrf_setconf:488: Note: rf_chain 1 configuration; en:1 freq:916500000 rssi_offset:-166.000000 radio_type:2 tx_enable:0 tx_notch_freq:0
loragw_pkt_logger: INFO: LoRa multi-SF channel 0 enabled, radio 1 selected, IF -400000 Hz, 125 kHz bandwidth, SF 7 to 12
lgw_rxif_setconf:607: Note: LoRa 'multi' if_chain 0 configuration; en:1 freq:-400000 SF_mask:0x7e
loragw_pkt_logger: INFO: LoRa multi-SF channel 1 enabled, radio 1 selected, IF -200000 Hz, 125 kHz bandwidth, SF 7 to 12
lgw_rxif_setconf:607: Note: LoRa 'multi' if_chain 1 configuration; en:1 freq:-200000 SF_mask:0x7e
loragw_pkt_logger: INFO: LoRa multi-SF channel 2 enabled, radio 1 selected, IF 0 Hz, 125 kHz bandwidth, SF 7 to 12
lgw_rxif_setconf:607: Note: LoRa 'multi' if_chain 2 configuration; en:1 freq:0 SF_mask:0x7e
loragw_pkt_logger: INFO: LoRa multi-SF channel 3 enabled, radio 0 selected, IF -400000 Hz, 125 kHz bandwidth, SF 7 to 12
lgw_rxif_setconf:607: Note: LoRa 'multi' if_chain 3 configuration; en:1 freq:-400000 SF_mask:0x7e
loragw_pkt_logger: INFO: LoRa multi-SF channel 4 enabled, radio 0 selected, IF -200000 Hz, 125 kHz bandwidth, SF 7 to 12
lgw_rxif_setconf:607: Note: LoRa 'multi' if_chain 4 configuration; en:1 freq:-200000 SF_mask:0x7e
loragw_pkt_logger: INFO: LoRa multi-SF channel 5 enabled, radio 0 selected, IF 0 Hz, 125 kHz bandwidth, SF 7 to 12
lgw_rxif_setconf:607: Note: LoRa 'multi' if_chain 5 configuration; en:1 freq:0 SF_mask:0x7e
loragw_pkt_logger: INFO: LoRa multi-SF channel 6 enabled, radio 0 selected, IF 200000 Hz, 125 kHz bandwidth, SF 7 to 12
lgw_rxif_setconf:607: Note: LoRa 'multi' if_chain 6 configuration; en:1 freq:200000 SF_mask:0x7e
loragw_pkt_logger: INFO: LoRa multi-SF channel 7 enabled, radio 0 selected, IF 400000 Hz, 125 kHz bandwidth, SF 7 to 12
lgw_rxif_setconf:607: Note: LoRa 'multi' if_chain 7 configuration; en:1 freq:400000 SF_mask:0x7e
loragw_pkt_logger: INFO: LoRa standard channel enabled, radio 1 selected, IF -200000 Hz, 250000 Hz bandwidth, SF 7
lgw_rxif_setconf:581: Note: LoRa 'std' if_chain 8 configuration; en:1 freq:-200000 bw:2 dr:2
loragw_pkt_logger: INFO: FSK channel enabled, radio 1 selected, IF 300000 Hz, 125000 Hz bandwidth, 50000 bps datarate
lgw_rxif_setconf:637: Note: FSK if_chain 9 configuration; en:1 freq:300000 bw:3 dr:50000 (50000 real dr) sync:0xC194C1
loragw_pkt_logger: INFO: global_conf.json does contain a JSON object named gateway_conf, parsing gateway parameters
loragw_pkt_logger: INFO: gateway MAC address is configured to AA555A0000000000
loragw_pkt_logger: INFO: found local configuration file local_conf.json, trying to parse it
loragw_pkt_logger: INFO: local_conf.json does not contain a JSON object named SX1301_conf
loragw_pkt_logger: INFO: local_conf.json does contain a JSON object named gateway_conf, parsing gateway parameters
loragw_pkt_logger: INFO: gateway MAC address is configured to AA555A0000000101
ERROR: FAIL TO CONNECT BOARD
loragw_pkt_logger: ERROR: failed to start the concentrator

Pin assign is failure?

will127534, 2019-05-15:
please also open DEBUG_REG
I forgot DEBUG_REG is the actual underlying interaction between SPI and SX1301.

himitu23, 2019-05-15:
I also got that(DEBUG_REG = 1);

pi@ttn-gateway:~/lora_gateway/util_pkt_logger $ ./util_pkt_logger
...
loragw_pkt_logger: INFO: local_conf.json does not contain a JSON object named SX1301_conf
loragw_pkt_logger: INFO: local_conf.json does contain a JSON object named gateway_conf, parsing gateway parameters
loragw_pkt_logger: INFO: gateway MAC address is configured to AA555A0000000101
ERROR CONNECTING CONCENTRATOR
ERROR: FAIL TO CONNECT BOARD
loragw_pkt_logger: ERROR: failed to start the concentrator

will127534, 2019-05-15:
Did you run ./reset_lgw.sh start before starting the gw?

will127534, 2019-05-15:
It seems like connection issue though...

himitu23, 2019-05-15:
Yes, I run "./reset_lgw.sh start" properly.
Of course, enabled SPI.

pi@ttn-gateway:~/lora_gateway $ ./reset_lgw.sh  start
Accessing concentrator reset pin through GPIO25...
pi@ttn-gateway:~/lora_gateway $ cd util_pkt_logger/
pi@ttn-gateway:~/lora_gateway/util_pkt_logger $ ls
Makefile  global_conf.json  inc  local_conf.json  obj  readme.md  src  util_pkt_logger
pi@ttn-gateway:~/lora_gateway/util_pkt_logger $ ./util_pkt_logger

himitu23, 2019-05-15:
Here is GPIO mapping;

pi@ttn-gateway:~ $ gpio readall
 +-----+-----+---------+------+---+---Pi 3B--+---+------+---------+-----+-----+
 | BCM | wPi |   Name  | Mode | V | Physical | V | Mode | Name    | wPi | BCM |
 +-----+-----+---------+------+---+----++----+---+------+---------+-----+-----+
 |     |     |    3.3v |      |   |  1 || 2  |   |      | 5v      |     |     |
 |   2 |   8 |   SDA.1 | ALT0 | 1 |  3 || 4  |   |      | 5v      |     |     |
 |   3 |   9 |   SCL.1 | ALT0 | 1 |  5 || 6  |   |      | 0v      |     |     |
 |   4 |   7 | GPIO. 7 |   IN | 1 |  7 || 8  | 1 | ALT5 | TxD     | 15  | 14  |
 |     |     |      0v |      |   |  9 || 10 | 1 | ALT5 | RxD     | 16  | 15  |
 |  17 |   0 | GPIO. 0 |   IN | 0 | 11 || 12 | 0 | IN   | GPIO. 1 | 1   | 18  |
 |  27 |   2 | GPIO. 2 |   IN | 0 | 13 || 14 |   |      | 0v      |     |     |
 |  22 |   3 | GPIO. 3 |   IN | 0 | 15 || 16 | 0 | IN   | GPIO. 4 | 4   | 23  |
 |     |     |    3.3v |      |   | 17 || 18 | 0 | IN   | GPIO. 5 | 5   | 24  |
 |  10 |  12 |    MOSI |   IN | 0 | 19 || 20 |   |      | 0v      |     |     |
 |   9 |  13 |    MISO |   IN | 0 | 21 || 22 | 0 | IN   | GPIO. 6 | 6   | 25  |
 |  11 |  14 |    SCLK |   IN | 0 | 23 || 24 | 1 | IN   | CE0     | 10  | 8   |
 |     |     |      0v |      |   | 25 || 26 | 1 | IN   | CE1     | 11  | 7   |
 |   0 |  30 |   SDA.0 |   IN | 1 | 27 || 28 | 1 | IN   | SCL.0   | 31  | 1   |
 |   5 |  21 | GPIO.21 |   IN | 0 | 29 || 30 |   |      | 0v      |     |     |
 |   6 |  22 | GPIO.22 |   IN | 1 | 31 || 32 | 0 | IN   | GPIO.26 | 26  | 12  |
 |  13 |  23 | GPIO.23 |   IN | 0 | 33 || 34 |   |      | 0v      |     |     |
 |  19 |  24 | GPIO.24 |   IN | 0 | 35 || 36 | 0 | IN   | GPIO.27 | 27  | 16  |
 |  26 |  25 | GPIO.25 |   IN | 0 | 37 || 38 | 0 | IN   | GPIO.28 | 28  | 20  |
 |     |     |      0v |      |   | 39 || 40 | 0 | IN   | GPIO.29 | 29  | 21  |
 +-----+-----+---------+------+---+----++----+---+------+---------+-----+-----+
 | BCM | wPi |   Name  | Mode | V | Physical | V | Mode | Name    | wPi | BCM |
 +-----+-----+---------+------+---+---Pi 3B--+---+------+---------+-----+-----+

navinyate, 2019-05-15:
Have u checked the NSS pin, is it connected to the right pin!

On Wed, 15 May, 2019, 23:17 tokina (himitu), <notifications@github.com>
wrote:

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

navinyate, 2019-05-15:
Is your local_conf.json file correct, because I don't see Ur device
connection to any lora backed server and still working with
global_conf.jskn file.

On Wed, 15 May, 2019, 22:48 tokina (himitu), <notifications@github.com>
wrote:

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

will127534, 2019-05-16:
Can you double check the soldering between the board and the pins?

himitu23, 2019-05-16:
Sorry, I cannot check because I don't have a tester..

himitu23, 2019-05-22:
It run succesfully with remounting the HAT, thanks.

Closed 2019-05-22.

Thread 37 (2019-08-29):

Calibration Failure, Status =7

hatefdm, 2019-08-29:
Hi
I'm facing Calibration Failure, Status =7  when running test_loragw_cal with the following result, so the concentrator does not start.
============================
Library version information: Version: 5.0.1;
Radio type: 2
Radio A frequency: 867.500000 MHz
Radio B frequency: 868.500000 MHz
Number of calibration iterations: 5
Calibration command: brd: 0, chip: 1257, dac: 3

WARNING: problem in calibration of radio A for image rejection
WARNING: Calibration not finished
Rx A IQ mismatch: Amp:   0 Phi:   0 Rej:  0 dB Status:   7 | Debug: Rej:  0 dB Lna: 0 BB:  0 Dec:  0
WARNING: problem in calibration of radio A for image rejection
WARNING: Calibration not finished
Rx A IQ mismatch: Amp:   0 Phi:   0 Rej:  0 dB Status:   7 | Debug: Rej:  0 dB Lna: 0 BB:  0 Dec:  0
WARNING: problem in calibration of radio A for image rejection
WARNING: Calibration not finished
Rx A IQ mismatch: Amp:   0 Phi:   0 Rej:  0 dB Status:   7 | Debug: Rej:  0 dB Lna: 0 BB:  0 Dec:  0
WARNING: problem in calibration of radio A for image rejection
WARNING: Calibration not finished
Rx A IQ mismatch: Amp:   0 Phi:   0 Rej:  0 dB Status:   7 | Debug: Rej:  0 dB Lna: 0 BB:  0 Dec:  0
WARNING: problem in calibration of radio A for image rejection
WARNING: Calibration not finished
Rx A IQ mismatch: Amp:   0 Phi:   0 Rej:  0 dB Status:   7 | Debug: Rej:  0 dB Lna: 0 BB:  0 Dec:  0

WARNING: problem in calibration of radio B for image rejection
WARNING: Calibration not finished
Rx B IQ mismatch: Amp:   0 Phi:   0 Rej:  0 dB Status:   7 | Debug: Rej:  0 dB Lna: 0 BB:  0 Dec:  0
WARNING: problem in calibration of radio B for image rejection
WARNING: Calibration not finished
Rx B IQ mismatch: Amp:   0 Phi:   0 Rej:  0 dB Status:   7 | Debug: Rej:  0 dB Lna: 0 BB:  0 Dec:  0
WARNING: problem in calibration of radio B for image rejection
WARNING: Calibration not finished
Rx B IQ mismatch: Amp:   0 Phi:   0 Rej:  0 dB Status:   7 | Debug: Rej:  0 dB Lna: 0 BB:  0 Dec:  0
WARNING: problem in calibration of radio B for image rejection
WARNING: Calibration not finished
Rx B IQ mismatch: Amp:   0 Phi:   0 Rej:  0 dB Status:   7 | Debug: Rej:  0 dB Lna: 0 BB:  0 Dec:  0
WARNING: problem in calibration of radio B for image rejection
WARNING: Calibration not finished
Rx B IQ mismatch: Amp:   0 Phi:   0 Rej:  0 dB Status:   7 | Debug: Rej:  0 dB Lna: 0 BB:  0 Dec:  0

Tx A calibration bypassed

Tx B calibration bypassed

Rx A IQ mismatch calibration statistics on   5 iterations (min, max):
Amp:   0   0 Phi:   0   0 Rej:  0  0 dB (capt.:  0  0 dB)

Rx B IQ mismatch calibration statistics on   5 iterations (min, max):
Amp:   0   0 Phi:   0   0 Rej:  0  0 dB (capt.:  0  0 dB)

End of radio calibration test
=========================
I've run util_spi_stress successfully for multiple hours. We have ordered the bare PCB and assembled the board.  Any ideas what the problem can be?

will127534, 2019-08-31:
You might want to double-check the connection between SX1257 and SX1301/1308
Moreover, make sure that the 32Mhz TCXO clock is running, and the power is stable (Note: util_spi_stress doesn't really power-up the power-hungry stuff )

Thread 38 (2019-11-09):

LoRa-concentrator RPI Zero v3 BOM on octopart

bkrajendra, 2019-11-09:
Im trying to figure out right parts for this design.
Im sharing this BOM from Octopart, if any one can suggest if its ok, it will be good to buy the item.
https://octopart.com/bom-tool/LadeLROL

will127534, 2019-11-10:
OSC2 should be TCXO and package size should be 3.2mm x 2.5mm, and OSC1 should be 2.0mm x 2.5mm.
I use SiTime's product for the hight speed 133Mhz 2025 OSC.
Also, recommend changing SX1301 to SX1308 to save some cost.

Haven't checked the passive components but seems ok.

bkrajendra, 2019-11-10:
@will127534  thanks a lot for quick response.
I did replaced SX1308, but could not find exact part numbers for both OCX1 and OCX2
I found [this ](https://www.sitime.com/datasheet/2025)for 133Mhz , but it looks like SOT-23 package.
could no find 32mhz tcxo in 3.2x2.5mm type.

bkrajendra, 2019-11-18:
I did manage to find these two close match from microchips reference design:
OCX1 - https://www.ndk.com/images/products/catalog/c_2725T_lan_e.pdf - SKU - 644-1331-1-ND

OCX2 - https://www.jauch.com/downloadfile/57ff72b1b7707_2612e42791cc621776f7/jt33v_v6_171027_online.pdf - SKU - 1908-1045-1-ND

I hope these two make sense.

bkrajendra, 2019-11-18:
I just updated my BoM on octoparts.

will127534, 2019-11-18:
Just to note that the OSC size of the reference design is bigger than the Osc on the RPI-Zero version.
There isn't much space on the RPI-Zero version for me to squeeze the original Osc...

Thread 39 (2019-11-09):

How to adapt it for Frequency Plan IN865 for India

bkrajendra, 2019-11-09:
Hi i want adapt and make changes to this board for India IN865
Will it be sufficient to change following filters:
U$8,U$4,U$9  and
U$6
if yes what would proper value/model number for it.

and  do we need to change any other component.?

will127534, 2019-11-18:
I'm not sure which SAW filter you need to use for IN865
But just make sure that the passband for the SAW filter is in the range of  IN865.
Other components can stay the same.

bkrajendra, 2019-11-20:
I found this one.
http://52ebad10ee97eea25d5e-d7d40819259e7d3022d9ad53e3694148.r84.cf3.rackcdn.com/UK_ACT_ACTDF8137-865-0-QCC8C_DS.pdf

it has center frequency of 865Mhz

Dharm94, 2021-04-18:
@bkrajendra Brother did you tried this for IN865??? is it working??

bkrajendra, 2021-04-18:
not yet. COVID happened. and they left the work on this project due to all these chip market issues.
But I am willing to start it again. It's really nice project.
Currently, I am using RakWireless RPI GW.

I am planning to convert it to KiCad.
I Will update you if I get any success with this.

Closed 2019-11-18.

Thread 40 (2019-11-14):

LoRa concentrator failed to start

kungfupizza, 2019-11-14:
Hi,
Since the production stopped, I printed my own PCB without no changes in the given schematics. When I test it, I still get "main: LoRa concentrator failed to start".

Am I missing something!?

bkrajendra, 2019-11-18:
Hi @kungfupizza  I am also trying to assemble my own board for rpi zero.
Can you help me regarding few component selection.
Im not finding OCX1 and OCX2 part numbers.
It will be great if you can tell me which parts number your using  or links to purchase for these two oscillators.
I can also help you in testing and resolving the issue.
You can find my entire list of BoM at :
https://octopart.com/bom-tool/LadeLROL
suggest any change if you think it can be made better.

will127534, 2019-11-18:
You can enable the debug output from lora_gateway/libloragw/library.cfg
And see which component failed.

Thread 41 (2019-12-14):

[main] failed to start the concentrator

abhinav-2307, 2019-12-14:
*** Beacon Packet Forwarder for Lora Gateway ***
Version: 4.0.1
*** Lora concentrator HAL library version info ***
Version: 5.0.1;
***
INFO: Little endian host
INFO: found global configuration file global_conf.json, parsing it
INFO: global_conf.json does contain a JSON object named SX1301_conf, parsing SX1                                                                                        301 parameters
INFO: lorawan_public 1, clksrc 1
INFO: no configuration for LBT
INFO: antenna_gain 0 dBi
INFO: Configuring TX LUT with 16 indexes
INFO: radio 0 enabled (type SX1257), center frequency 865200000, RSSI offset -16                                                                                        6.000000, tx enabled 1, tx_notch_freq 129000
INFO: radio 1 enabled (type SX1257), center frequency 866385000, RSSI offset -16                                                                                        6.000000, tx enabled 0, tx_notch_freq 0
INFO: Lora multi-SF channel 0>  radio 0, IF -137500 Hz, 125 kHz bw, SF 7 to 12
INFO: Lora multi-SF channel 1>  radio 0, IF 202500 Hz, 125 kHz bw, SF 7 to 12
INFO: Lora multi-SF channel 2>  radio 1, IF -400000 Hz, 125 kHz bw, SF 7 to 12
INFO: Lora multi-SF channel 3 disabled
INFO: Lora multi-SF channel 4 disabled
INFO: Lora multi-SF channel 5 disabled
INFO: Lora multi-SF channel 6 disabled
INFO: Lora multi-SF channel 7 disabled
INFO: Lora standard channel 8 disabled
INFO: FSK channel 8 disabled
INFO: global_conf.json does contain a JSON object named gateway_conf, parsing ga                                                                                        teway parameters
INFO: server hostname or IP address is configured to "router.as.thethings.networ                                                                                        k"
INFO: upstream port is configured to "1700"
INFO: downstream port is configured to "1700"
INFO: packets received with a valid CRC will be forwarded
INFO: packets received with a CRC error will NOT be forwarded
INFO: packets received with no CRC will NOT be forwarded
INFO: GPS serial port path is configured to "/dev/serial0"
INFO: found local configuration file local_conf.json, parsing it
INFO: redefined parameters will overwrite global parameters
INFO: local_conf.json does not contain a JSON object named SX1301_conf
INFO: local_conf.json does contain a JSON object named gateway_conf, parsing gat                                                                                        eway parameters
INFO: gateway MAC address is configured to B827EBFCEDF9DAE7
INFO: packets received with a valid CRC will be forwarded
INFO: packets received with a CRC error will NOT be forwarded
INFO: packets received with no CRC will NOT be forwarded
INFO: [main] TTY port /dev/serial0 open for GPS synchronization
ERROR: [main] failed to start the concentrator

abhinav-2307, 2019-12-14:
Dec 13 14:16:31 lora_gateway mtp-probe: checking bus 1, device 4: "/sys/devices/platform/soc/3f980000.usb/usb1/1-1/1-1.1/1-1.1.1"
Dec 13 14:16:31 lora_gateway mtp-probe: bus: 1, device: 4 was not an MTP device
Dec 13 14:16:31 lora_gateway mtp-probe: checking bus 1, device 4: "/sys/devices/platform/soc/3f980000.usb/usb1/1-1/1-1.1/1-1.1.1"
Dec 13 14:16:31 lora_gateway mtp-probe: bus: 1, device: 4 was not an MTP device
Dec 13 14:16:34 lora_gateway lightdm[437]: Error getting user list from org.freedesktop.Accounts: GDBus.Error:org.freedesktop.DBus.Error.ServiceUnknown: The name org.f$
Dec 13 14:16:36 lora_gateway lightdm[495]: Error getting user list from org.freedesktop.Accounts: GDBus.Error:org.freedesktop.DBus.Error.ServiceUnknown: The name org.f$

after entering cd /var/log/
nano user.log.1
so,i wanted find the exact isuues and solution for this .
and ehat is lightdm error

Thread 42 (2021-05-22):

Did anyone made one recently

wujiang, 2021-05-22:
First and foremost, huge thanks to the author @will127534 for all the work!

I'm trying to get the BOM ready and send the design to jlcpcb. Wondering if anyone made this recently so that we can share some resources.

asprakash, 2021-08-21:
Hi @wujiang .
I am also interested on this board. But unable to invest on this project since the main developer did not confirmed whether this board (as per the design files released) is working or not. However, I can fix the issues on the existing board since I am experienced on various boards like RAKWireless, NiceRF, iC880A, Sandbox,.etc. I need a board (with fully soldered) for testing purpose and I can fix the issues & make it work. May others can also join with us, @abhinav-2307 @kungfupizza @bkrajendra and others.

TIA

bkrajendra, 2021-08-22:
I am also in.
We can either fork this repo or create a new one and start working on it. I am good with KiCad, we can start design review first and then can order some from JLCPCB.
let make a group and start working.
let me know what you think.?

will127534, 2021-08-22:
Just adding comment that it is working - The board file released is the same as the one I sold on Tindle.
Also note that I have another board https://github.com/will127534/LoRa-GW-FeatherWing based on Kicad already.

asprakash, 2021-08-23:
Hi @will127534 Thanks for your comment and confirmation from your side. I will also go through the featherwing project.

@bkrajendra Thanks for your interest. Instead of starting from scratch, let us focusing on the existing issues and how to solve them since @will127534 already confirmed that this PCB should be working fine when you are using the same design & components. Rest, the issues may be relevant to linux stuff. I would like to get one sample board from anyone instead of fabricating the PCB. Bcoz sourcing the entire BOM is taking more time, components shortage/delay everywhere.  May I know if you have one for testing.

TIA

bkrajendra, 2021-08-23:
Yes, ok for me to focus on existing issues.
I am also struggling with components.
I will try if my Chinese vendor can supply it.

will127534, 2021-08-23:
IMAO, I think you need to change the DC-DC and LDO parts anyway because of the silicon shortages.

bhaktatejas922, 2021-11-18:
@will127534 How much did the board cost you to make ?

kongeo-aueb, 2022-02-24:
> Hi @wujiang . I am also interested on this board. But unable to invest on this project since the main developer did not confirmed whether this board (as per the design files released) is working or not. However, I can fix the issues on the existing board since I am experienced on various boards like RAKWireless, NiceRF, iC880A, Sandbox,.etc. I need a board (with fully soldered) for testing purpose and I can fix the issues & make it work. May others can also join with us, @abhinav-2307 @kungfupizza @bkrajendra and others.
>
> TIA

I am interested in asking you for some modufication advice on a Rak board.
I cannot contact you first
Here is my email kon123geo@gmail.com
Thank you in advance.

samuk, 2022-03-28:
Is anyone interested in moving this forward still? Did any boards get made?

My personal interest is using the Pi Zero version with this [Banana pi Zero](https://forum.banana-pi.org/t/lora-for-m2-zero/13202) for a fully open hardware device.

How complex would it be to adapt to newer LoRa chips such as SX1278?

naturalmechanics, 2022-08-21:
I am interested.

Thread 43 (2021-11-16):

Hi will

gadLinux, 2021-11-16:
I was using your board V3 with my rpi for a looong time.
I just migrated to ttnv3 and using t-impulse watch to do some tests. The packet forwarder seems to register right in TTN but when the watch tries to register we send back a bad message to the watch. I suppose that's a gateway trouble, because the libraries are open, ttn is tested by thousands and the only piece in the middle is the gateway...

arduino-lmic sees the message but ev_t ev value enum is strange and changes in every registration...

See something like 1257164: Unknown event

Do you think that packet forwarder or gateway library is still ok?

will127534, 2021-11-16:
Can you lay down the software/library steps so I can reproduce or ask you to provide more logs by changing some library debug info?

gadLinux, 2021-11-17:
Hi Will,
Yes, I followed the guide:
 * https://github.com/will127534/LoRa-concentrator/wiki/Startup-Guide
The Gateway is connected to TTN v3 and it shows it's live!
   https://ttnmapper.org/heatmap/private/?gateway=fe000100ff000001&network=NS_TTS_V3://ttn@000013
So that's a good thing
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

I can see Join request on TTN and in the gateway

JSON down: {"txpk":{"imme":false,"tmst":463689596,"freq":868.1,"rfch":0,"powe":14,"modu":"LORA","datr":"SF8BW125","codr":"4/5","ipol":true,"size":33,"ncrc":true,"data":"IOwUXX8rfaim5TUqK6X0jPGtg6gF4Xz0Q/16C4DLDq/P"}}

But it fails on device... because the kind of message is not expected.

I think that on device the code is pretty much standard:

https://github.com/Xinyuan-LilyGO/LilyGo-T-Impulse/blob/master/Example/T-Impulse-S76G-LoRaWAN/src/loramac.cpp

gadLinux, 2021-11-17:
Some logs too:
##### 2021-11-17 10:30:57 GMT #####
### [UPSTREAM] ###
# RF packets received by concentrator: 0
# CRC_OK: 0.00%, CRC_FAIL: 0.00%, NO_CRC: 0.00%
# RF packets forwarded: 0 (0 bytes)
# PUSH_DATA datagrams sent: 1 (113 bytes)
# PUSH_DATA acknowledged: 100.00%
### [DOWNSTREAM] ###
# PULL_DATA sent: 6 (100.00% acknowledged)
# PULL_RESP(onse) datagrams received: 0 (0 bytes)
# RF packets sent to concentrator: 0 (0 bytes)
# TX errors: 0
# TX rejected (collision packet): 0.00% (req:1, rej:0)
# TX rejected (collision beacon): 0.00% (req:1, rej:0)
# TX rejected (too late): 0.00% (req:1, rej:0)
# TX rejected (too early): 100.00% (req:1, rej:1)
# BEACON queued: 0
# BEACON sent so far: 0
# BEACON rejected: 0
### [JIT] ###
# SX1301 time (PPS): 92277009
src/jitqueue.c:448:jit_print_queue(): INFO: [jit] queue is empty
### [GPS] ###
# Invalid time reference (age: 1637145057 sec)
# no valid GPS coordinates available yet
##### END #####

will127534, 2021-11-18:
> But it fails on device... because the kind of message is not expected.
Any error log on the device side?

gadLinux, 2021-11-18:
Yes. But it's supposed to be tested with another gateway. So I better bet for a gateway problem because, protocol, outdated server, etc... Nobody reported something similar?
I was looking at the forum and see something about pushing wrong mensajes because temperature in the lora chip, I don't know if this can affect.

I will try debug device a little bit. Before getting again to the gateway. Can you confirm if the gateway correctly works with TTN v3? Anyone tested.

Thank you anyway for your support Will

gadLinux, 2021-11-20:
I added logs on device... And it seems nothing arrives...

Will check why

will127534, 2021-11-20:
> I will try debug device a little bit. Before getting again to the gateway. Can you confirm if the gateway correctly works with TTN v3? Anyone tested.

Nope, I haven't update my gw for a while, and I didn't tested with TTN v3.

I kind of wondering if it is related to pulse per second settings, does TTN v3 require accurate time pulse for downlink Tx?

gadLinux, 2021-11-20:
Finally I found the problem. And it was caused by me.
I added a delay in the main loop to see debug messages. And it delayed all processing missing the join messages. Sorry for causing troubles.

And thank you again for your support.

I can confirm the gateway and software is working with TTN3

Closed 2021-11-20.

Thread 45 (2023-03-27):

Which crystal oscillator?

elektronika-ba, 2023-03-27:
Hello,

I can't find the part number for the crystal oscillators used for SX1255 and SX1257. Can you tell me which one you used in the design?

The datasheet of SX125x IC states that it must be 1.8V peek to peek sinewave. Adding capacitor in series might solve this, however the maximum voltage would still be 3.3V relative to GND. Don't know if this is OK or I am missing something.

Thanks

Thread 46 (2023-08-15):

Library to program this gateway/Sketch example for Raspberry

Andynopol, 2023-08-15:
Hello, @will127534! Do you have an official library for this board and some examples to go with? Thanks!

will127534, 2023-08-16:
[Wiki](https://github.com/will127534/LoRa-concentrator/wiki)

As for the original question: The project is not dead, it's finished. It has been running on the roof for some time now, and I'm satisfied with the board so no further dev is needed.

Andynopol, 2023-08-16:
Sorry. Is this concentrator able to receive signals from multiple bandwidths(125kHz, 250kHz, 500kHz) and all spreding factors (from 7 to 12) at the same time?

This is what I am assuming reading the CONCENTRATOR term, so I just want to be sure.

And also I would like to know where can I order one?

mikini, 2023-08-16:
At least it has been available from Will on Tindie in the incarnations below;

* [Raspberry Pi LoRa Gateway](https://www.tindie.com/products/will123321/sx1308-raspberry-pi-lora-gateway-board/)
* [Raspberry Pi LoRa Gateway, bare PCB](https://www.tindie.com/products/will123321/bare-pcb-for-rpi-lora-gateway-v3-two-boards/)
* [Raspberry Pi Zero LoRa Gateway (smaller PCB by using single chip amplifier)](https://www.tindie.com/products/will123321/sx1308-raspberry-pi-zero-lora-gateway-board/)

To my knowledge not currently sold anywhere, but I have previously seen copies/variations of them available from different manufacturers. I have not followed LoRa development closely, but I guess new chipsets could have been released making this design obsolete/uninteresting. Maybe Will can answer that?

The Tindie product page/reviews contain some valuable information, but see also these threads;
* https://www.thethingsnetwork.org/forum/t/finished-opensource-raspberry-pi-gateway-hat-sx1301-8-base/10994/1
* https://www.thethingsnetwork.org/forum/t/sx1308-pi-gateway/13047/2

The Raspberry Pi GPIO/J8 header is [electrically identical across "1 Models A+ and B+, 2 Model B, 3 Models A+, B and B+, 4, and Zero WH and Zero W 2"](https://en.wikipedia.org/wiki/Raspberry_Pi#J8_header_and_general_purpose_input-output_(GPIO)), although probably there could be potential mechanical fitting issues lurking.

Andynopol, 2023-08-16:
The SX1303 is still used in products like Rak5146. So the obsolete problem I believe is far from being a concern

will127534, 2023-08-17:
Yeah why not? Is it based on SX1301/SX1308.

will127534, 2023-08-17:
For newer chipset though it is for another project: [https://github.com/will127534/LoRa-GW-FeatherWing](https://github.com/will127534/LoRa-GW-FeatherWing)

I don't see the point using RPI for LoRa GW so I end up building one for more MCU orientated board, but you can use it on RPI (I did that for HW testing)

Andynopol, 2023-08-17:
I understand. For now I'll try this one and if I am not satisfied with the results, I'll just get the other one. Right now I am trying to order the board on [https://jlcpcb.com](JLCPCB) and I have Total 72 parts detected ,38 Parts confirmed, 3 parts Inventory shortage, 31 parts not selected. Do you have another recomandation from where can I order it or the BOM and CLS files needs an update?

will127534, 2023-08-18:
It looks like you are not that familiar with HW from scratch, so I highly recommend you look at off-the-shelf options like the Rak5146 you've mention.

This project, in general is to serve as the base for custom gateway design, like if you want a different frequency for some weird reason, or different board formfactor for other SBC/MCU boards or just you want to integrate fully to some design.

I won't update the BOM and CPL because the batch I've sell on Tindle is build with that BOM and CPL, this serves as a reference for those who've brought the board and want to check the parts. Also the format is not for JLCPCB (Yeah I know, but this is before JLCPCB PCBA have the chips I need for this build) but other PCBA factories.

In general, you might just use Rak5146 or something from RAK that fits, it will be easier for you to use. This project is for those who likes/needs to tinker with the GW design.

Andynopol, 2023-08-19:
I have a RAK5146 board. The problem that I have with it is that I am trying to connect to a personal application. Not Chirptsack/TTN. The problem that I have with this product is that is overly complicated when it comes to connecting to someple personal projects(is just a gateway, not a damn company with departaments and services - that is a small part of my frustration with this board). The documentation is a royal mess. The RAK5146 has the least amount of documentation compare to the 2XXX and 7XXX lineup.

That is why I was aiming for an opensource version.
Plus, there are bonus points if I don't use an off the shelf version for my final product on my exam.

Note: I was not expecting you to change the BOM in the repo, but to check if you can send me an updated version for JLCPCB or whatever PCBA factory.

I will try on my own. I was just trying to cheat a little bit of time...I guess. Sorry!

will127534, 2023-08-20:
The thing is, you can run the libloragw and it's helper program on those HW (RAK5146 ) that you don't have to connect to The Things Network. Probably just need to check the GPIO connections on the SX1303 and you are good to go and use either USB or SPI.

You will need to first understand the structure of these LoRa GW (SW and HW) before you proceed this route. And there is no point of catching the bonus point if you can't even get the thing to work at the first place.

Closed 2023-08-16.

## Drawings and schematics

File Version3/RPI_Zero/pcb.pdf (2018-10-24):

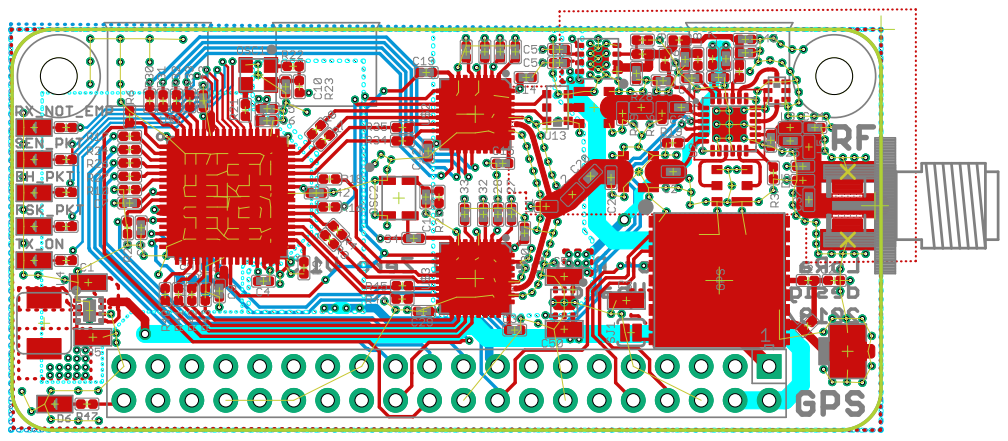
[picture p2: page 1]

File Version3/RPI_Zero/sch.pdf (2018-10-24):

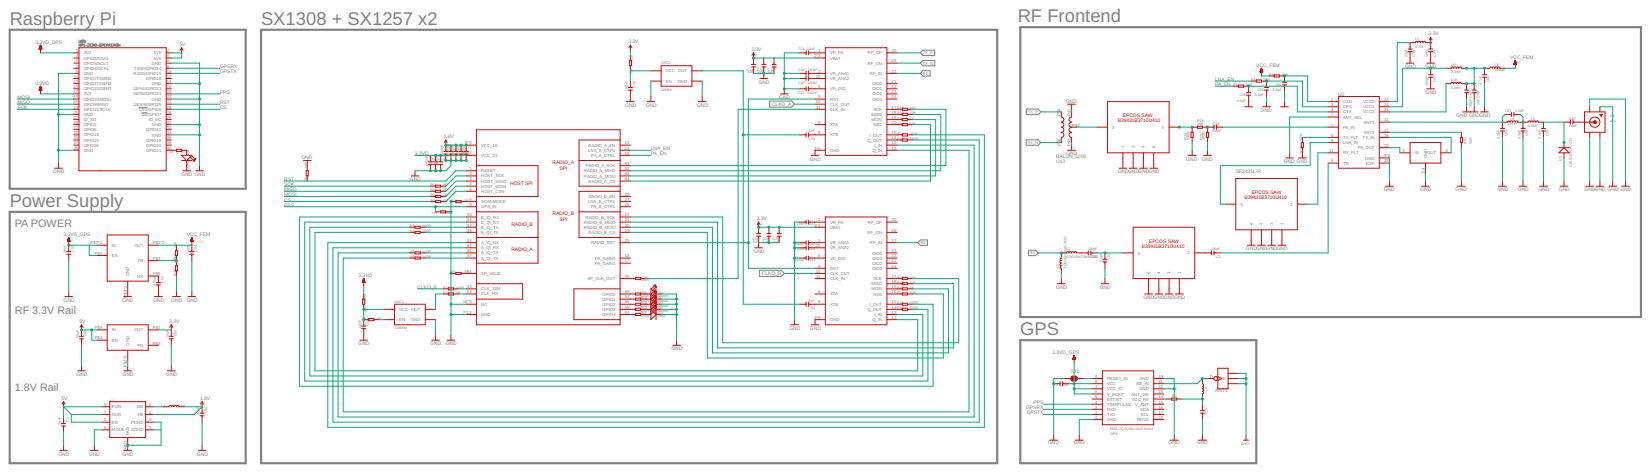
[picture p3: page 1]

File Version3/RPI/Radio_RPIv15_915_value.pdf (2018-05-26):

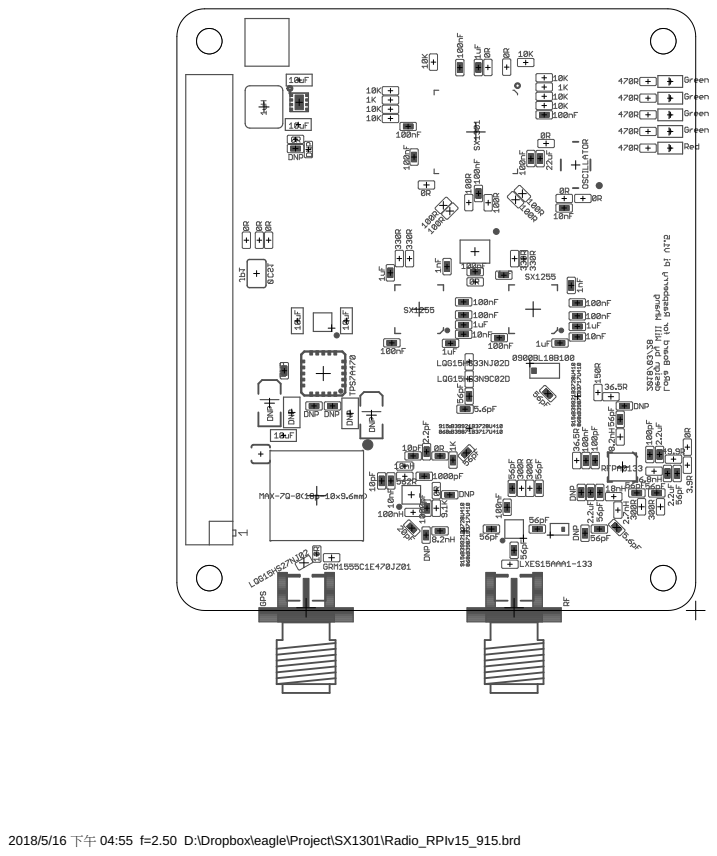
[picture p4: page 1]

2018/5/16 下午 04:55 f=2.50 D:\Dropbox\eagle\Project\SX1301\Radio_RPIv15_915.brd

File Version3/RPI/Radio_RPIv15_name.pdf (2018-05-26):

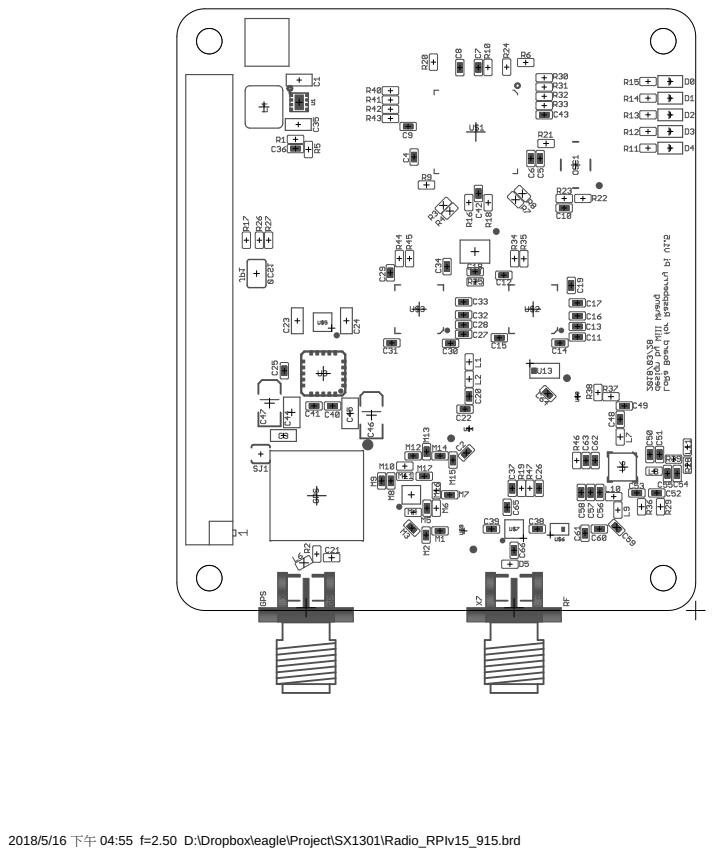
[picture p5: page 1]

2018/5/16 下午 04:55 f=2.50 D:\Dropbox\eagle\Project\SX1301\Radio_RPIv15_915.brd

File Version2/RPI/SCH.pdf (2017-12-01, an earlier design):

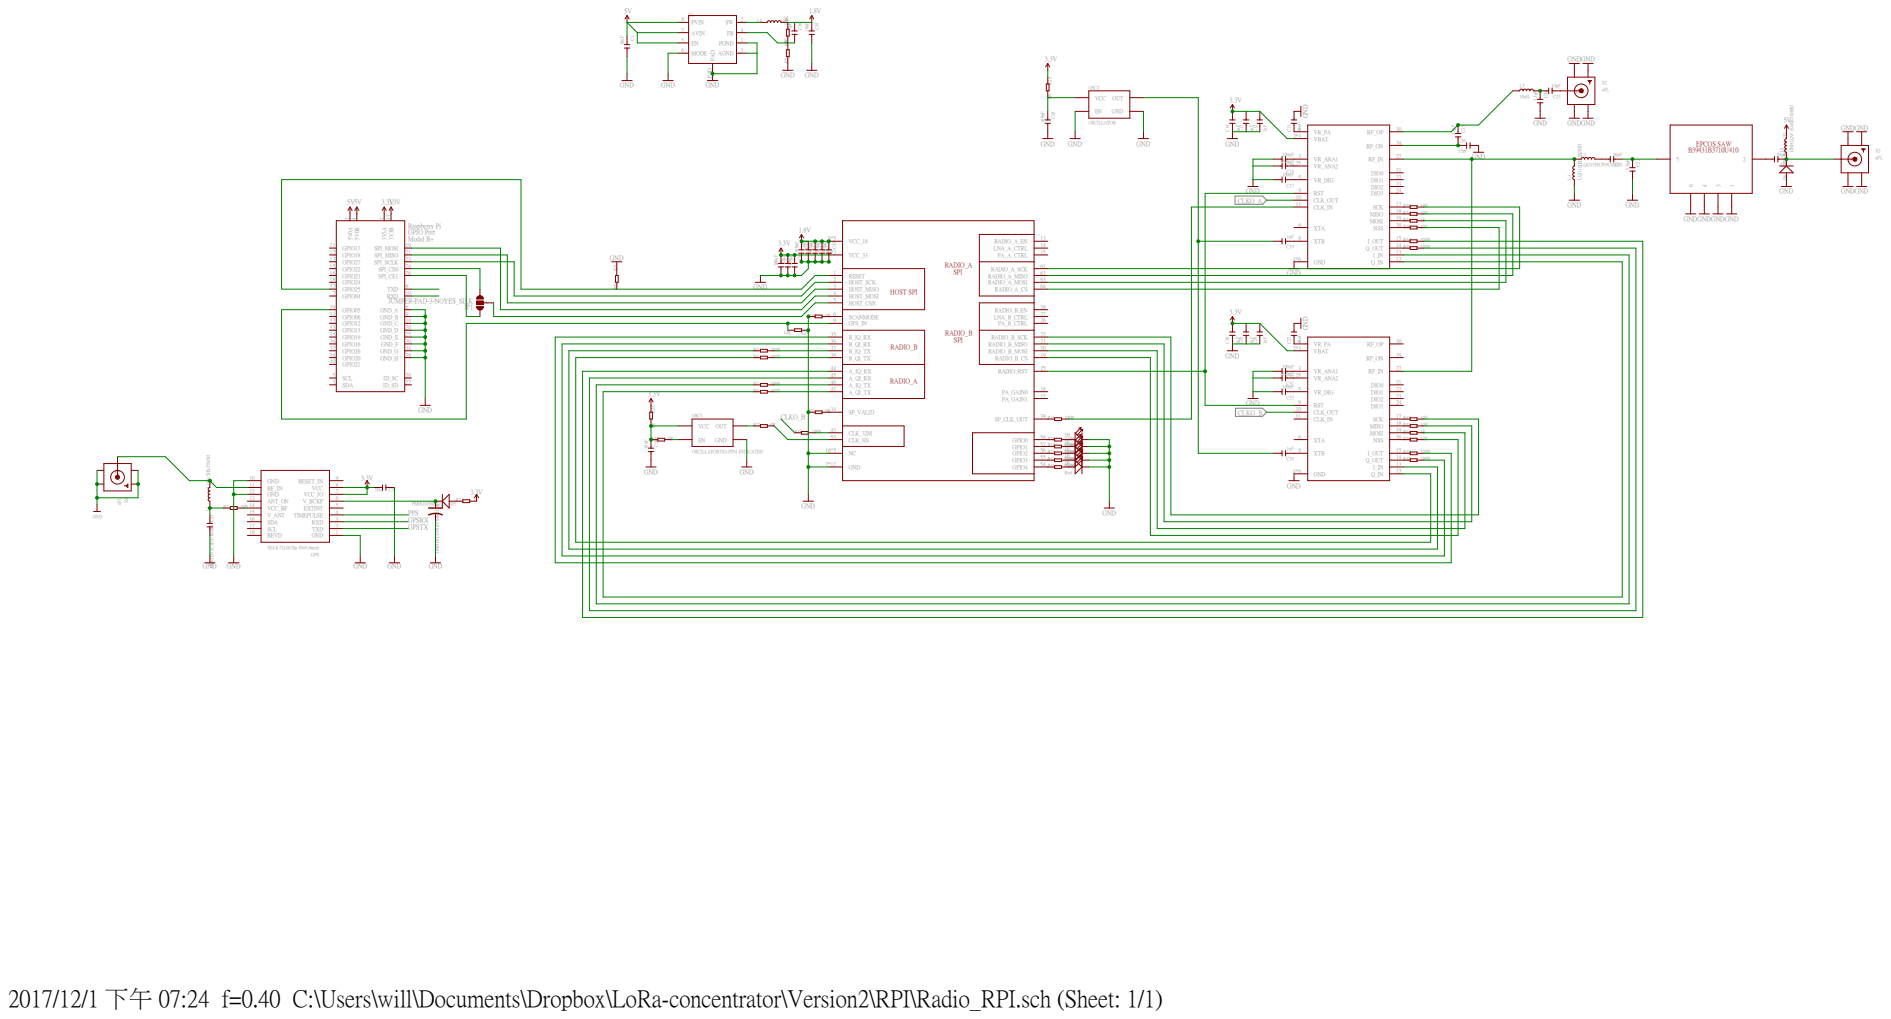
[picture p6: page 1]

Raspberry Pi GPIO Port Model B+

Red Green Green Green Green

2017/12/1 下午 07:24 f=0.40 C:\Users\will\Documents\Dropbox\LoRa-concentrator\Version2\RPI\Radio_RPI.sch (Sheet: 1/1)

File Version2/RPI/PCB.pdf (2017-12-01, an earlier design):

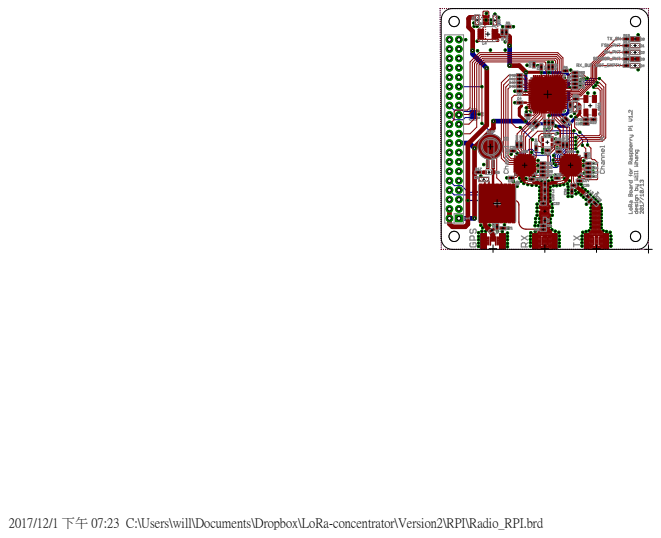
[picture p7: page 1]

2017/12/1 下午 07:23 C:\Users\will\Documents\Dropbox\LoRa-concentrator\Version2\RPI\Radio_RPI.brd

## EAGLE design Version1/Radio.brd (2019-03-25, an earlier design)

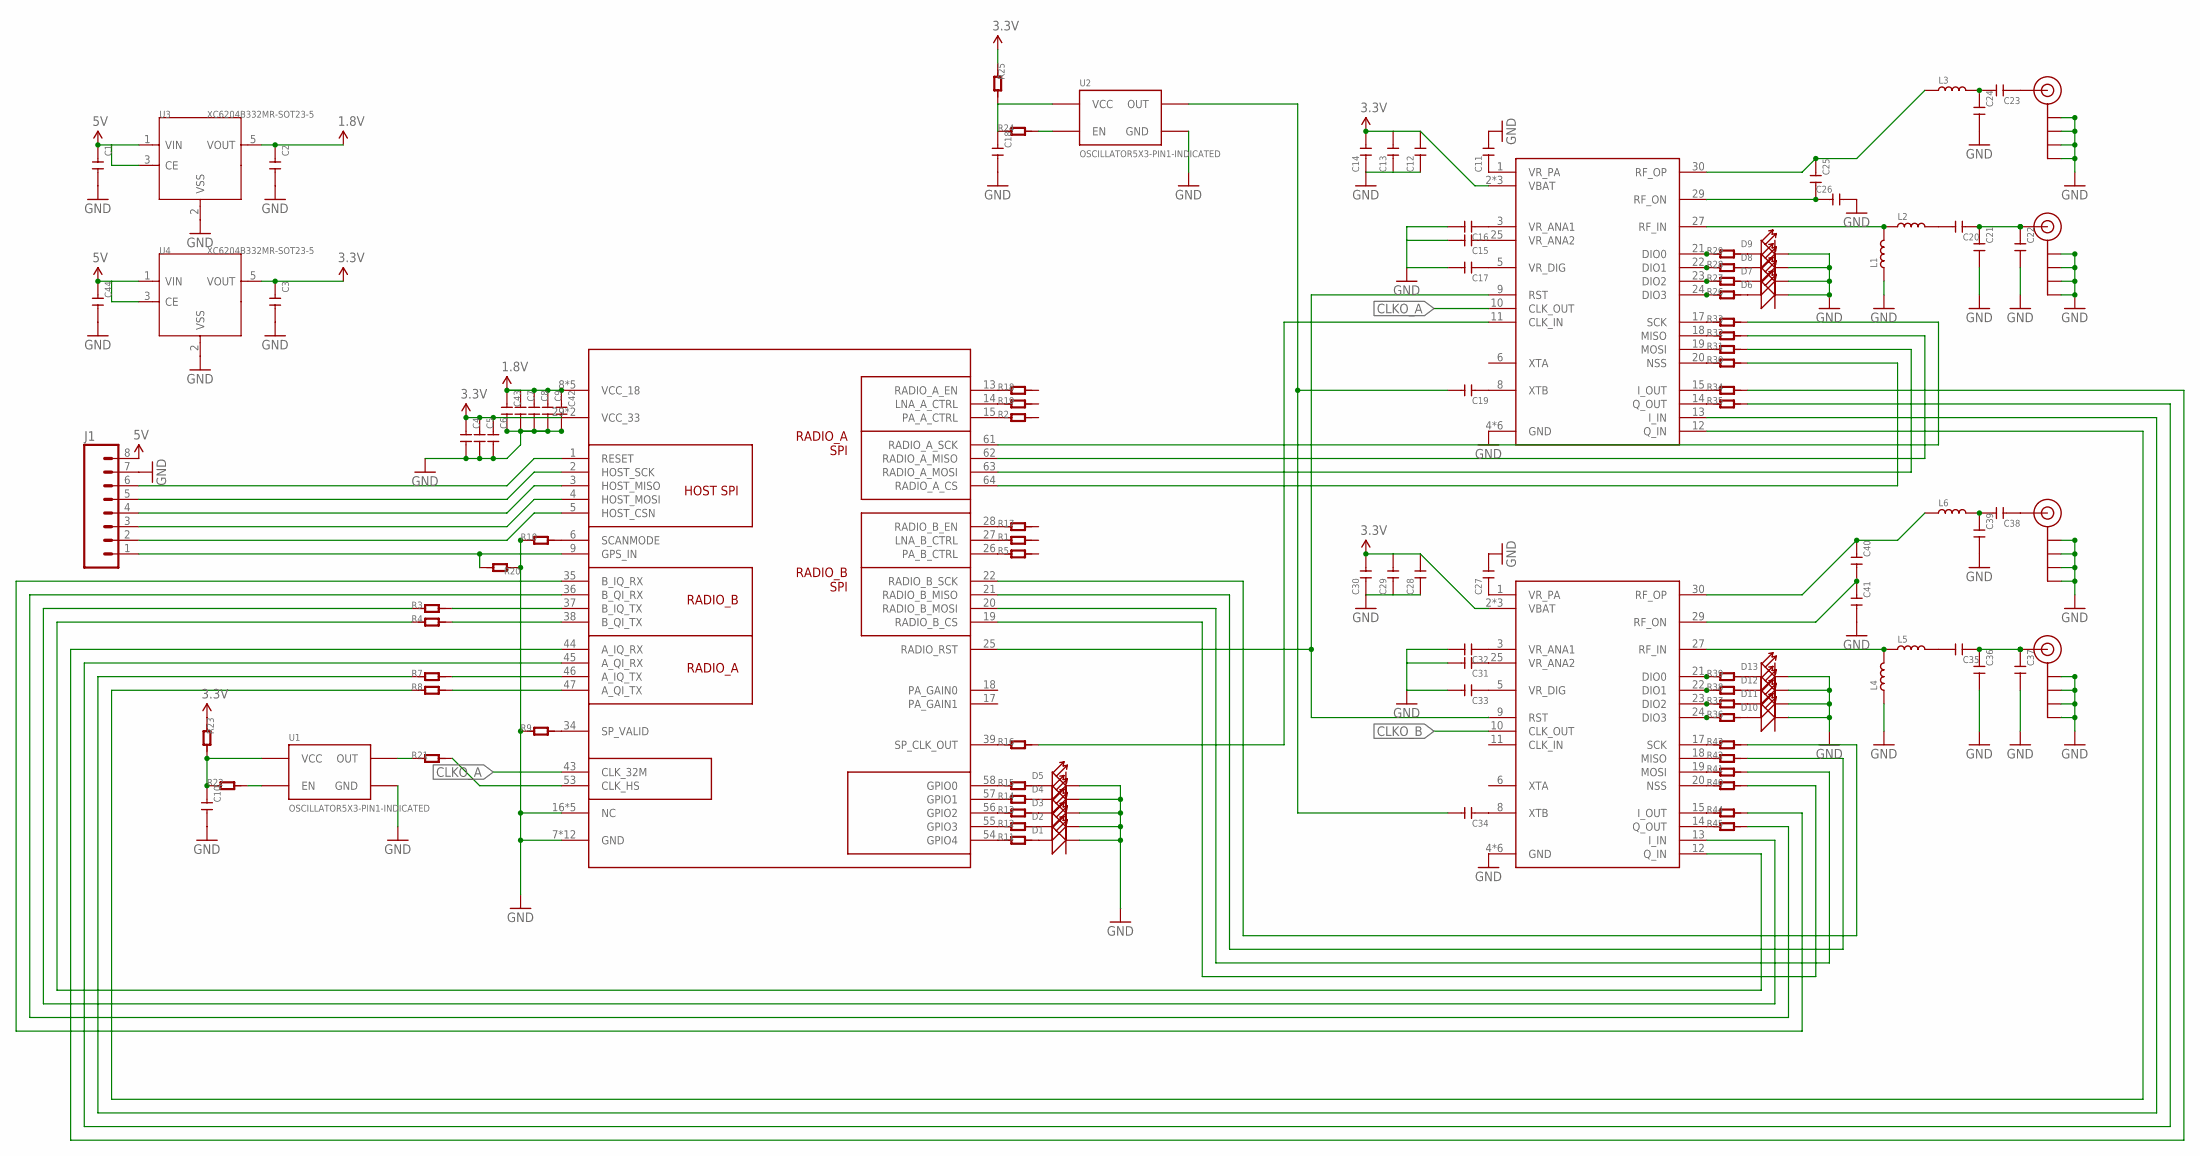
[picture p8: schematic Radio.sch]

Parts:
C1, C3: CAP-0603; C0603
C2, C4, C6, C7, C8, C9, C10, C11, C12, C13, C14, C15, C16, C17, C18, C19, C20, C21, C22, C23, C24, C25, C26, C27, C28, C29, C30, C31, C32, C33, C34, C35, C36, C37, C38, C39, C40, C41, C42, C43, C44: CAP-0402; C0402
C5: CAP-0805; C0805
D1, D2, D3, D4, D5, D6, D7, D8, D9, D10, D11, D12, D13: LED-0402
J1: M08LOCK; 1X08_LOCK
J$1, J$2, J$3, J$4: SMA_EDGE; SMA-EDGE
L1, L2, L3, L4, L5, L6: INDUCTOR/FERRITE-BEAD-0402; L0402
R1, R2, R3, R4, R5, R7, R8, R9, R10, R11, R12, R13, R14, R15, R16, R17, R18, R19, R20, R21, R22, R23, R24, R25, R26, R27, R28, R29, R30, R31, R32, R33, R34, R35, R36, R37, R38, R39, R40, R41, R42, R43, R44, R45: R-0402; R0402
U1, U2: OSCILLATOR5X3-PIN1-INDICATED; CRYSTAL-OSC-SMD-5X3
U3, U4: XC6204B332MR-SOT23-5; SOT-23-5
U$1: SX1301; QFN64G-0.5-9X9MM
U$2, U$3: SX1255; QFN32G-0.5-5X5MM

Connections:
1.8V: C2.1, C7.1, C8.1, C9.1, C42.1, C43.1, U3.5 (VOUT), U$1.8 (VCC_18), U$1.12 (VCC_18), U$1.23 (VCC_18), U$1.42 (VCC_18), U$1.60 (VCC_18)
3.3V: C3.1, C4.1, C5.1, C6.1, C12.2, C13.2, C14.2, C28.2, C29.2, C30.2, R23.1, R25.1, U4.5 (VOUT), U$1.29 (VCC_33), U$1.52 (VCC_33), U$2.2 (VBAT), U$2.16 (VBAT), U$2.32 (VBAT), U$3.2 (VBAT), U$3.16 (VBAT), U$3.32 (VBAT)
5V: C1.1, C44.1, J1.8, U3.1 (VIN), U3.3 (CE), U4.1 (VIN), U4.3 (CE)
CLKO_A: U$1.43 (CLK_32M), U$2.10 (CLK_OUT)
CLKO_B: U$3.10 (CLK_OUT)
CS: J1.2, U$1.5 (HOST_CSN)
GND: C1.2, C2.2, C3.2, C4.2, C5.2, C6.2, C7.2, C8.2, C9.2, C10.2, C11.2, C12.1, C13.1, C14.1, C15.2, C16.2, C17.2, C18.2, C21.2, C22.2, C24.2, C26.2, C27.2, C28.1, C29.1, C30.1, C31.2, C32.2, C33.2, C36.2, C37.2, C39.2, C41.2, C42.2, C43.2, C44.2, D1.-, D2.-, D3.-, D4.-, D5.-, D6.-, D7.-, D8.-, D9.-, D10.-, D11.-, D12.-, D13.-, J1.7, J$1.GND@0 (GND), J$1.GND@1 (GND), J$1.GND@2 (GND), J$1.GND@3 (GND), J$2.GND@0 (GND), J$2.GND@1 (GND), J$2.GND@2 (GND), J$2.GND@3 (GND), J$3.GND@0 (GND), J$3.GND@1 (GND), J$3.GND@2 (GND), J$3.GND@3 (GND), J$4.GND@0 (GND), J$4.GND@1 (GND), J$4.GND@2 (GND), J$4.GND@3 (GND), L1.1, L4.1, R9.1, R10.1, R20.1, U1.2 (GND), U2.2 (GND), U3.2 (VSS), U4.2 (VSS), U$1.7 (GND), U$1.10 (GND), U$1.11 (GND), U$1.16 (NC), U$1.24 (GND), U$1.30 (GND), U$1.31 (GND), U$1.32 (NC), U$1.33 (NC), U$1.40 (GND), U$1.41 (GND), U$1.48 (NC), U$1.49 (NC), U$1.50 (GND), U$1.51 (GND), U$1.59 (GND), U$1.65 (GND), U$2.4 (GND), U$2.7 (GND), U$2.26 (GND), U$2.28 (GND), U$2.31 (GND), U$2.33 (GND), U$3.4 (GND), U$3.7 (GND), U$3.26 (GND), U$3.28 (GND), U$3.31 (GND), U$3.33 (GND)
MISO: J1.4, U$1.3 (HOST_MISO)
MOSI: J1.3, U$1.4 (HOST_MOSI)
unnamed: R30.1, U$2.20 (NSS)
unnamed: R45.2, U$1.36 (B_QI_RX)
unnamed: R3.2, U$1.37 (B_IQ_TX)
unnamed: R4.2, U$1.38 (B_QI_TX)
unnamed: R34.2, U$1.44 (A_IQ_RX)
unnamed: R7.2, U$1.46 (A_IQ_TX)
unnamed: R8.2, U$1.47 (A_QI_TX)
unnamed: R35.2, U$1.45 (A_QI_RX)
unnamed: R9.2, U$1.34 (SP_VALID)
unnamed: R10.2, U$1.6 (SCANMODE)
unnamed: R1.1, U$1.27 (LNA_B_CTRL)
unnamed: R11.1, U$1.54 (GPIO4)
unnamed: R12.1, U$1.55 (GPIO3)
unnamed: R13.1, U$1.56 (GPIO2)
unnamed: R14.1, U$1.57 (GPIO1)
unnamed: R15.1, U$1.58 (GPIO0)
unnamed: D1.+, R11.2
unnamed: D2.+, R12.2
unnamed: D4.+, R14.2
unnamed: D5.+, R15.2
unnamed: D3.+, R13.2
unnamed: R16.1, U$1.39 (SP_CLK_OUT)
unnamed: R17.1, U$1.28 (RADIO_B_EN)
unnamed: R18.1, U$1.13 (RADIO_A_EN)
unnamed: R2.1, U$1.15 (PA_A_CTRL)
unnamed: R19.1, U$1.14 (LNA_A_CTRL)
unnamed: R5.1, U$1.26 (PA_B_CTRL)
unnamed: C19.1, U$2.8 (XTB)
unnamed: R21.2, U$1.53 (CLK_HS)
unnamed: R21.1, U1.3 (OUT)
unnamed: R22.2, U1.1 (EN)
unnamed: C10.1, R22.1, R23.2, U1.4 (VCC)
unnamed: R24.2, U2.1 (EN)
unnamed: C11.1, U$2.1 (VR_PA)
unnamed: C18.1, R24.1, R25.2, U2.4 (VCC)
unnamed: C19.2, C34.2, U2.3 (OUT)
unnamed: C15.1, U$2.25 (VR_ANA2)
unnamed: C16.1, U$2.3 (VR_ANA1)
unnamed: C17.1, U$2.5 (VR_DIG)
unnamed: R26.1, U$2.24 (DIO3)
unnamed: R27.1, U$2.23 (DIO2)
unnamed: R28.1, U$2.22 (DIO1)
unnamed: R29.1, U$2.21 (DIO0)
unnamed: D6.+, R26.2
unnamed: D8.+, R28.2
unnamed: D9.+, R29.2
unnamed: D7.+, R27.2
unnamed: L1.2, L2.1, U$2.27 (RF_IN)
unnamed: C20.2, L2.2
unnamed: C20.1, C21.1, C22.1, J$1.SIG (SIGNAL)
unnamed: C23.2, C24.1, L3.2
unnamed: C25.1, L3.1, U$2.30 (RF_OP)
unnamed: C25.2, C26.1, U$2.29 (RF_ON)
unnamed: C23.1, J$2.SIG (SIGNAL)
unnamed: R34.1, U$2.15 (I_OUT)
unnamed: R35.1, U$2.14 (Q_OUT)
unnamed: C27.1, U$3.1 (VR_PA)
unnamed: C31.1, U$3.25 (VR_ANA2)
unnamed: C32.1, U$3.3 (VR_ANA1)
unnamed: C33.1, U$3.5 (VR_DIG)
unnamed: C34.1, U$3.8 (XTB)
unnamed: R36.1, U$3.24 (DIO3)
unnamed: R37.1, U$3.23 (DIO2)
unnamed: R38.1, U$3.22 (DIO1)
unnamed: R39.1, U$3.21 (DIO0)
unnamed: D10.+, R36.2
unnamed: D12.+, R38.2
unnamed: D13.+, R39.2
unnamed: D11.+, R37.2
unnamed: L4.2, L5.1, U$3.27 (RF_IN)
unnamed: C35.2, L5.2
unnamed: C35.1, C36.1, C37.1, J$3.SIG (SIGNAL)
unnamed: C38.2, C39.1, L6.2
unnamed: C40.1, L6.1, U$3.30 (RF_OP)
unnamed: C40.2, C41.1, U$3.29 (RF_ON)
unnamed: C38.1, J$4.SIG (SIGNAL)
unnamed: R44.1, U$3.15 (I_OUT)
unnamed: R45.1, U$3.14 (Q_OUT)
unnamed: R33.2, U$1.61 (RADIO_A_SCK)
unnamed: R32.2, U$1.62 (RADIO_A_MISO)
unnamed: R31.2, U$1.63 (RADIO_A_MOSI)
unnamed: R30.2, U$1.64 (RADIO_A_CS)
unnamed: R43.2, U$1.22 (RADIO_B_SCK)
unnamed: R42.2, U$1.21 (RADIO_B_MISO)
unnamed: R41.2, U$1.20 (RADIO_B_MOSI)
unnamed: R40.2, U$1.19 (RADIO_B_CS)
unnamed: U$1.25 (RADIO_RST), U$2.9 (RST), U$3.9 (RST)
unnamed: R16.2, U$2.11 (CLK_IN)
unnamed: R44.2, U$1.35 (B_IQ_RX)
unnamed: R7.1, U$2.13 (I_IN)
unnamed: R3.1, U$3.13 (I_IN)
unnamed: R4.1, U$3.12 (Q_IN)
unnamed: R8.1, U$2.12 (Q_IN)
unnamed: R31.1, U$2.19 (MOSI)
unnamed: R32.1, U$2.18 (MISO)
unnamed: R33.1, U$2.17 (SCK)
unnamed: R40.1, U$3.20 (NSS)
unnamed: R41.1, U$3.19 (MOSI)
unnamed: R42.1, U$3.18 (MISO)
unnamed: R43.1, U$3.17 (SCK)
PPS: J1.1, R20.2, U$1.9 (GPS_IN)
RST: J1.6, U$1.1 (RESET)
SCK: J1.5, U$1.2 (HOST_SCK)

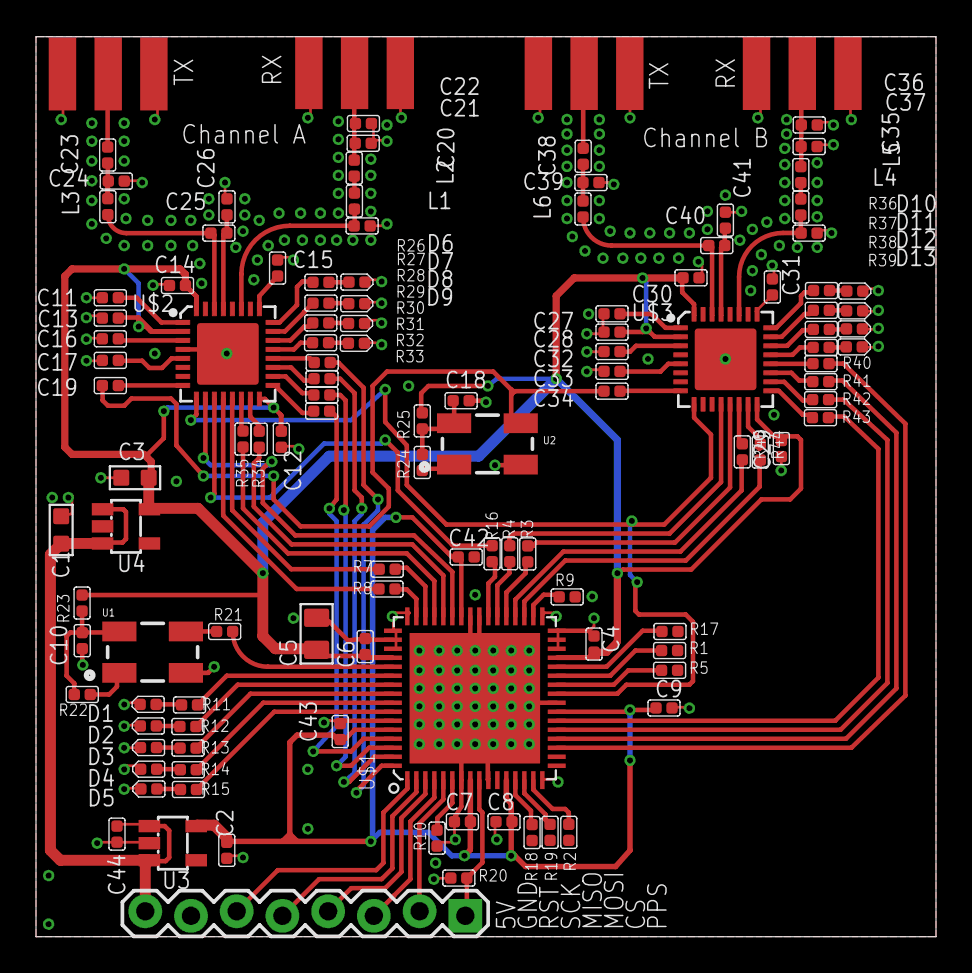
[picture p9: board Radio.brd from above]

Board: 2 copper layers, 50.0 x 50.0 mm, 119 parts (0 on the bottom side), 111 nets.

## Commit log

2016-08-29 upload Picture
    [Radio.GBL, Radio.GBO, Radio.GBP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]
2017-08-12 Adding Version 2
    Design for Raspberry Pi Zero
    [Radio_PIZero.brd, Radio_PIZero.sch]
2017-09-01 clean up
    [Radio.GBL, Radio.GBO, Radio.GBP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]
2017-12-01 release RPI Version
    [Radio_PIZero.brd, Radio_PIZero.sch, Radio_RPI.brd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]
2018-04-04 Add BOM file
    [BOM_V13.xlsx]
2018-05-26 Adding RPI V1.5
    [BOM.xlsx, Radio_RPIv15_915.brd, Radio_RPIv15_915.sch]
2018-10-24 Adding the smallest full setup Gateway for RPI Zero!
    [Radio_RPIZero.brd, Radio_RPIZero.sch]
2019-03-02 Fix the version problem of V3 RPI, the boards sellign on Tindle are updated
    [Radio_RPIv15_868.brd, Radio_RPIv15_868.sch]
2019-03-25 issue #30
    [BOM.xlsx, Radio.brd, Radio.sch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]
2019-04-05 Adding Gerber files

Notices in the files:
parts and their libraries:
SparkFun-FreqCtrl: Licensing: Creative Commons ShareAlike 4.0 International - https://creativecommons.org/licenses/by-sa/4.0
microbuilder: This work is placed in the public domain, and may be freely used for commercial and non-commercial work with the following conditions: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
